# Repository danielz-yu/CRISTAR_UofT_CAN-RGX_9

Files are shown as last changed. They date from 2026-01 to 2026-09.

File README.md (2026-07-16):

# CRISTAR UofT | CAN-RGX 9

CRISTAR aims to investigate laser-induced crystallization under both microgravity and hypergravity conditions. Our project will use a compact laser cavitation system to generate crystals under different gravity environments. We will then compare the size, structure and purity of the resulting lysozyme crystals to determine how gravity influences morphology and structural characteristics. This work aims to reduce the cost of microgravity-grown crystals by leveraging short-duration suborbital flights. 

#

**Team Members:**
- Alexander Wainwright
- Khaled Madhoun
- Elias Barsa
- Gabriel Caribé
- Syeda Mahdia
- Lauren Altomare
- Daniel Yu
- Natalie Djuric

[Canadian Reduced Gravity Experiment Design Challenge | 2025-2026 Teams](https://www.seds.ca/can-rgx/#current)

#

### Setup and Run

Main GUI script: `cristar_gui.py`  
Required dependencies: `requirements.txt`

### 1. Local Setup

```bash
python3 -m venv .venv
source .venv/bin/activate
pip install --upgrade pip
pip install -r requirements.txt
```

### 2. Running the Main GUI

Aliases set up on the Raspberry Pi
```bash
connections
gui
connections
start
```

If these aliases are unavailable in a non-interactive shell, run the script directly:
```bash
/home/cristar/Documents/GUI_Development.venv/bin/python /home/cristar/Documents/GUI_Development/cristar_gui.py
```

### 3. Testing Scripts

The `testing/` folder contains helper/testing scripts.
```bash
python3 Connections.py
```

### 4. Raspberry Pi Quick Access

- Pi hostname/user: `cristar@cristar.local`
- Pi password: `cristar2026`
- Alias available on the Pi setup: `gui` (runs the main GUI)
```bash
ssh cristar@cristar.local
gui
```

### 5. Remote GUI from a Second Computer (SSH + Ethernet/Wi-Fi + X11)

If running the GUI remotely from another computer (for example over Ethernet), install XQuartz and launch with X11 forwarding:
```bash
open -a XQuartz
export DISPLAY=:0
ssh -Y -o ForwardX11=yes -o ForwardX11Trusted=yes cristar@cristar.local
gui
```

#

<br>

<p align="center">
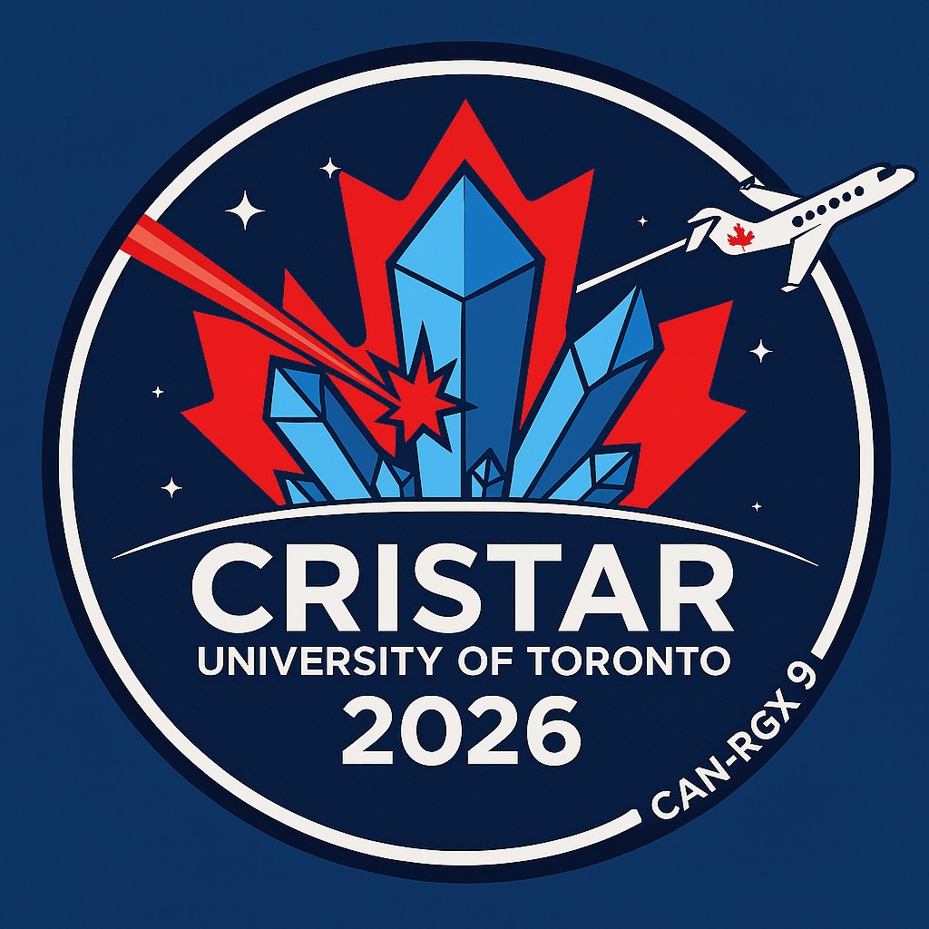
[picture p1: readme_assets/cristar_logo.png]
CRISTAR Logo
  </a>
  &nbsp;&nbsp;&nbsp;&nbsp;
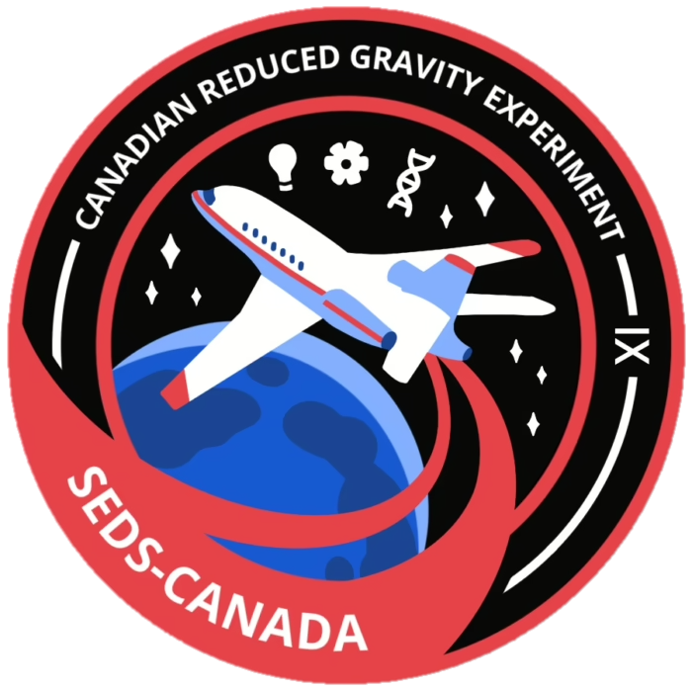
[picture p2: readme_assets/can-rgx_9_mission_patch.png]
CAN-RGX 9 Mission Patch
  </a>
</p>

<br>

<div align="center">
    <a href="https://www.seds.ca/can-rgx/">
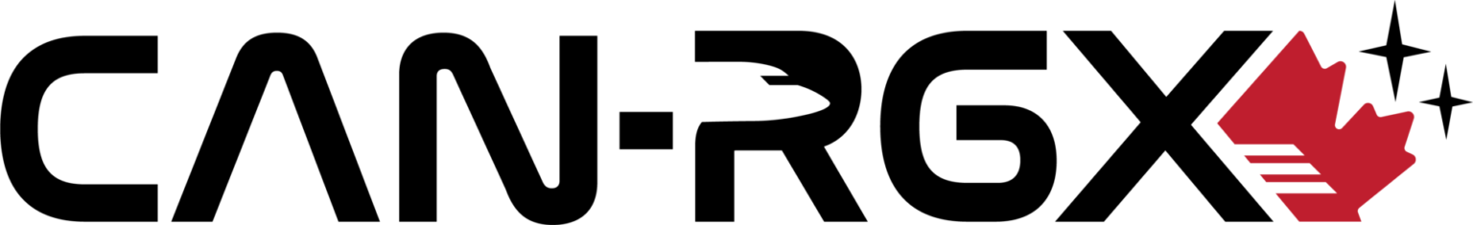
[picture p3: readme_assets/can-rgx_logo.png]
CAN-RGX Logo
        
    </a>
</div>

<br>

<div align="center">
    <a href="https://www.utoronto.ca/">
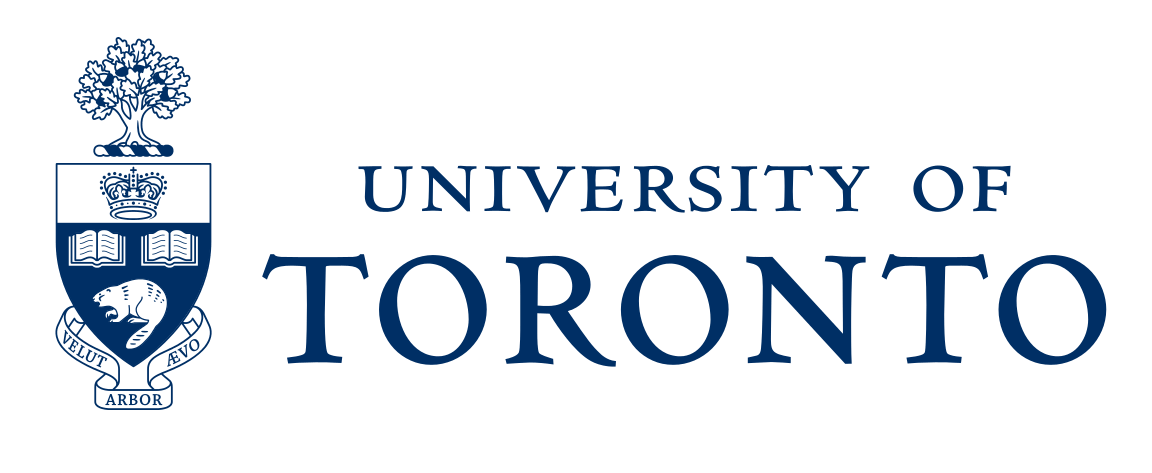
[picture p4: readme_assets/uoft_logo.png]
University of Toronto Logo
        
    </a>
</div>

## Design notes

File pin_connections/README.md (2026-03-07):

# Raspberry Pi 5 GPIO Connections

**SparkFun BME280**
- GPIO 1 (3V3)  --> 3V3
- GPIO 30 (GND) --> GND
- GPIO 2 (SDA)  --> SDA
- GPIO 3 (SCL)  --> SCL

**Adafruit BNO085**
- GPIO 1 (3V3)  --> VIN
- GPIO 39 (GND) --> GND
- GPIO 2 (SDA)  --> SDA
- GPIO 3 (SCL)  --> SCL

**Camera**

**Linear Stage**

**Laser**

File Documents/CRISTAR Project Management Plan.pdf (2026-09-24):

# Project Management Plan

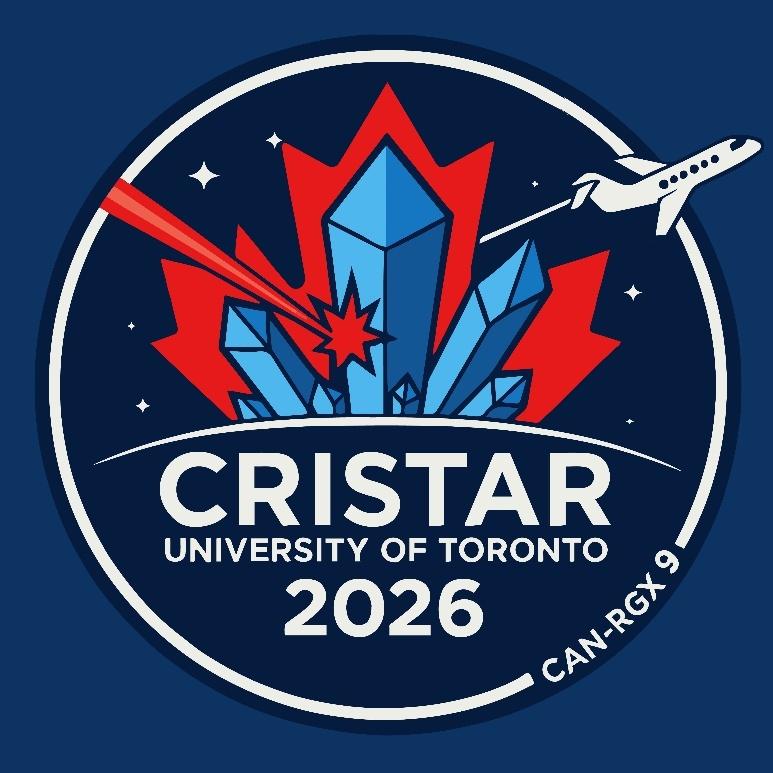
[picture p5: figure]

# CRISTAR

# University of Toronto

# Submitted in conformity with the requirements for the CAN-RGX IX program

# Submitted: December 30, 2025

# Executive Summary:

The CRISTAR project aims to study laser-induced crystallization under microgravity conditions as part of the CAN-RGX IX program. Crystallization is a critical process across multiple technological fields, and recent advances in laser-induced crystallization have enabled rapid, highly controlled crystal formation on Earth; however, the role of gravity in these processes remains poorly understood. By comparing the morphology and structural characteristics of crystals formed using laser-induced crystallization in a microgravity environment to those formed using the same technique on Earth, this project aims to advance the development of space-based crystallization techniques.

The CRISTAR team is composed of five undergraduate engineering students, two graduate physics students, and a supporting faculty advisor, all from the University of Toronto. To manage the technical requirements and timeline, the project is organized into five phases: design development, ground testing, pre-flight campaign, flight campaign, and post-flight review. Each phase includes clearly defined objectives, deliverables, and responsibilities, supported by a detailed work breakdown structure, timeline, and contingency protocols. Flight safety, laser safety, and experimental reliability are prioritized throughout the project lifecycle. A formal task reallocation and member recruitment process has been established to mitigate risks associated with team member availability and workload changes.

Budget requirements total $7,850 CAD, with a conservative fundraising target of $11,775 CAD after applying a 1.5x safety factor. Funding is pursued through a combination of “in-kind” donations, university funding programs, student organizational funding, and specialized industry support, with each member being responsible to secure funding for their area of expertise.

In parallel with technical objectives, the project emphasizes public engagement through ongoing in-person and digital outreach activities. These efforts aim to communicate the scientific and societal value of microgravity research to students and the broader community.

# Contents:

## Executive Summary: | 2 Introduction: Project Background | 4 Team structure and Management | 5 Team Members | 6 Task Reallocation Protocol | 7 Member Recruitment | 8 Project Timeline | 9 Time Management Protocol | 9 Project Time Allocation | 9 Budget and Funding | 13

Budget and funding strategy | Error! Bookmark not defined.

## References | 16

# List of Figures:

Figure 1: Work breakdown structure for project tasks and responsibilities for each member | 5
Figure 2: Step by step plan of action for task reallocation after a team member requests a reduction in
contribution expectations or is unable to continue their support of the CRISTAR project | 7
Figure 3:Step by step plan for the recruitment of team members which will be applied when new team

## members are required to support project goals | 8

# List of Tables:

Table 1: List of team members, including the faculty advisor, all from the University of Toronto, with

roles identified | 6 Table 2: Overview of the time allocations for each phase of the project | 10 Table 3: Time and task allocation for the design development phase | 11 Table 4: Time and task allocation for the ground testing phase | 12 Table 5: Time and task allocation for the flight campaign phase | 12 Table 6: Time and task allocation for the post flight phase of the project | 12

Table 7:Budget requirements for project components are travel costs are estimated and described. Shipping costs are planned to be covered by the Miller Lab and are not included in the budget below....14 Table 8: Funding Sources and Member Responsibilities: Each team member is accountable for securing resources related to their assigned engineering tasks. Responsibilities include identifying required
components and contacting suppliers to explore potential donations or discounts for those items | 15

# Introduction: Project Background

Crystallization is a foundational process in materials science, with applications in pharmaceutical drug development¹⁻⁵

, organic electronics⁶⁻⁸

, energy storage⁹,10, and semiconductor manufacturing¹¹. Interest in space-based crystallization processes is on the rise and has developed into a distinct part of the space industry¹²⁻¹⁶. A promising new ground-based technique involves laser-induced crystallization¹⁷, where short-lived bubbles rapidly reduce pressure and trigger nucleation. This method shortens crystal formation time from hours to seconds, with enhanced control over crystal size¹⁸, offering potential for high-throughput production of nano- and microcrystals¹⁸. However, the role of gravity in these dynamics, especially in laser-induced methods, remains poorly understood. Clarifying this influence is important for advancing space-based manufacturing and improving Earth-based simulations of space-grown materials.

This research aims to demonstrate laser-based crystallization in a microgravity environment and to compare the resulting crystal structures with those formed on Earth. The experiment will assess whether laser-induced crystallization under microgravity conditions accelerates crystal formation and enhances sample quality relative to Earth-grown crystals. These insights are particularly relevant for producing crystals suitable for diffraction-based structural determination using electron beams, which are now sufficiently compact and portable for spaceflight applications.

Key stakeholders include pharmaceutical companies that depend on high-quality crystals for drug development¹⁻⁵

, Canadian startups looking for new niches in the space industry¹⁹, and the Canadian Space Agency, which supports research that strengthens Canada’s role in the emerging space economy. Environmental considerations are also important. The proposed laser-based crystallization approach requires only short suborbital flights to produce thousands of samples, rather than relying on traditional orbital missions. Laser induced crystallization would reduce the number of satellites in low Earth orbit, mitigating space debris, require less fuel per flight, lower the overall environmental impact of space-based crystallization processes, and decrease operational costs.

The motivation behind this experiment is to lay the groundwork for scalable crystallization techniques in space, enabling space-based manufacturing, high-throughput screening and structural analysis using electron diffraction. By bridging fundamental science with engineering implementation, this research addresses critical questions about gravity’s role in materials science.

The goal of the proposed experiment is to demonstrate the production of microcrystals using laser cavitation-based crystallization in a short-duration microgravity environment, and to compare them to crystals produced using the same technique under Earth’s gravity. This objective includes demonstrating that laser-induced crystallization can reliably occur in microgravity and determining whether gravity influences the morphology and structural characteristics of the resulting crystals.

# Team structure and Management

CRISTAR is a team of seven students at the university of Toronto, with one faculty advisor. The team consists of two graduate students from the department of physics, and five undergraduate students from the Department of Engineering. To ensure the successful completion of our project objectives, task have been distributed as outlined in the work breakdown structure in Figure 1, with role assignment being given in Table 1. Roles were allocated according to areas of expertise and interest. We decided to have concrete roles to make job alignment and accountability straightforward. However, everyone is expected to help outside of their role when needed since interdisciplinary collaboration is at the centre of the team ethos.

The work breakdown structure in Figure 1 is written in terms of lines of effort instead of the five project phases to better illustrate the team workload distribution.

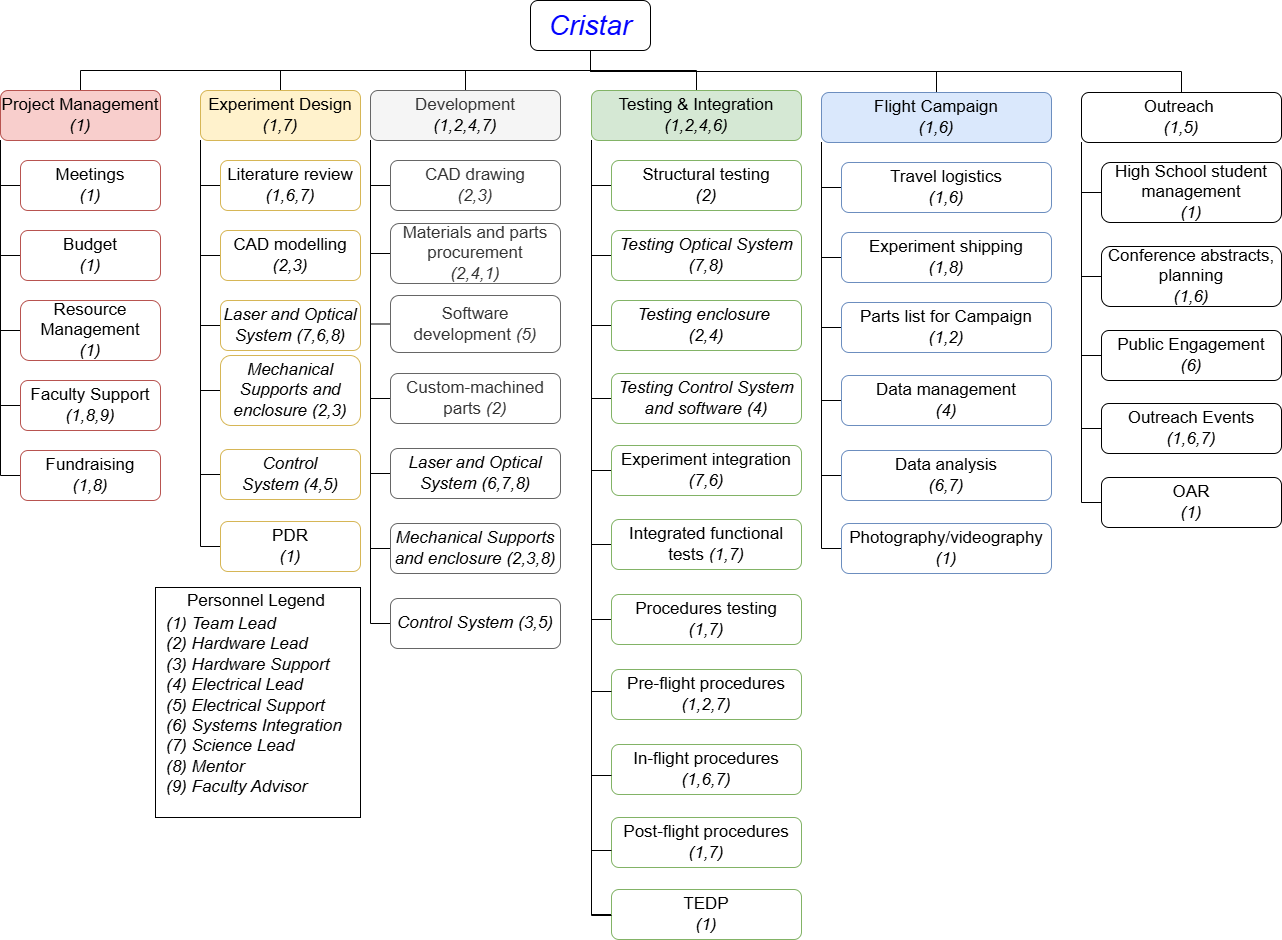
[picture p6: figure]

Figure 1: Work breakdown structure for project tasks and responsibilities for each member.

## Page 6/17

## Team Members

Table 1: List of team members, including the faculty advisor, all from the University of Toronto, with roles identified.

First, Last Name | Degree in progress | Level of Study | Department | Role | Email
Alexander, Wainwright | Ph.D. | Graduate | Physics | Team Lead | Alexander.Wainwright@mail.utoronto.ca
Syeda, Mahdia | BASc. | Undergraduate | Engineering Sciences | Science Lead | Syeda.Mahdia @mail.utoronto.ca
Lauren, Altomare | BASc. | Undergraduate | Engineering Sciences | Systems Integration | Lauren.Altomare@mail.utoronto.ca
Daniel, Yu | BASc. | Undergraduate | Computer Engineering | Electrical and Hardware Support | Danielz.Yu@mail.utoronto.ca
Elias, Barsa | BASc. | Undergraduate | Engineering Sciences | Hardware Lead | Elias.Barsa@mail.utoronto.ca
Gabriel, Caribe | BASc. | Undergraduate | Engineering Sciences | Electrical Lead | G.Caribe@mail.utoronto.ca
Khaled, Madhoun | Ph.D. | Graduate | Physics | Mentor | Khaled.Madhoun@mail.utoronto.ca
R.J. Dwayne, Miller | - | University Professor | Physics & Chemistry | Faculty Advisor | Dwayne.Miller@utoronto.ca

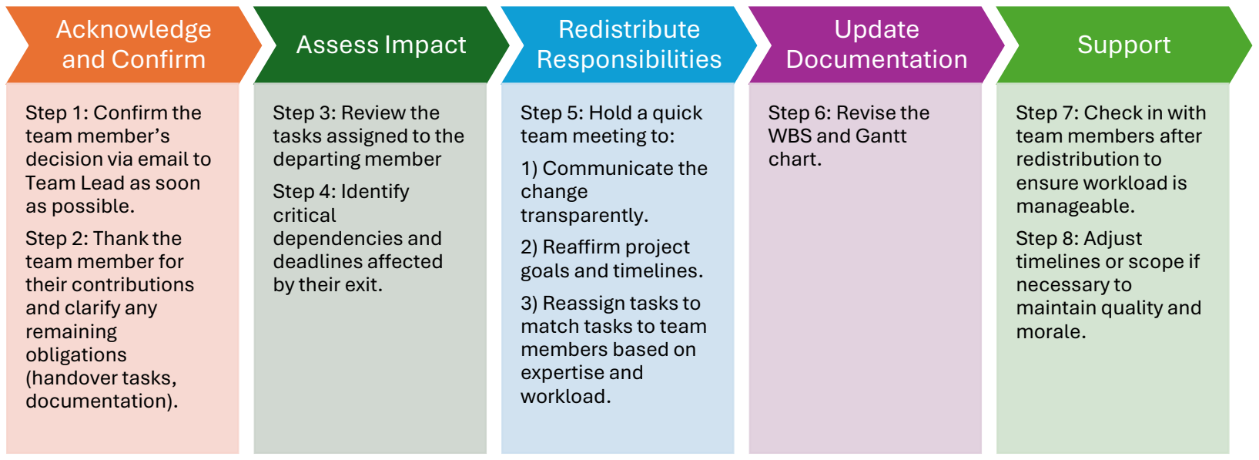
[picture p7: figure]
Acknowledge and Confirm; Step 1: Confirm the team member’s decision via email to Team Lead as soon as possible. Step 2: Thank the team member for their contributions and clarify any remaining obligations (handover tasks, documentation).; Assess Impact; Step 3: Review the tasks assigned to the departing member Step 4: Identify critical dependencies and deadlines affected by their exit.; Redistribute Responsibilities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

## Page 7/17

## Task Reallocation Protocol

Contingency planning is key to project success. As life changes may prevent CRISTAR members from continuing their commitment to the team, we have developed a task reallocation protocol, shown in Figure 2, to be followed if team members require a reduction in tasks or are unable to continue their commitment to the project.

Figure 2: Step by step plan of action for task reallocation after a team member requests a reduction in contribution expectations or is unable to continue their support of the CRISTAR project.

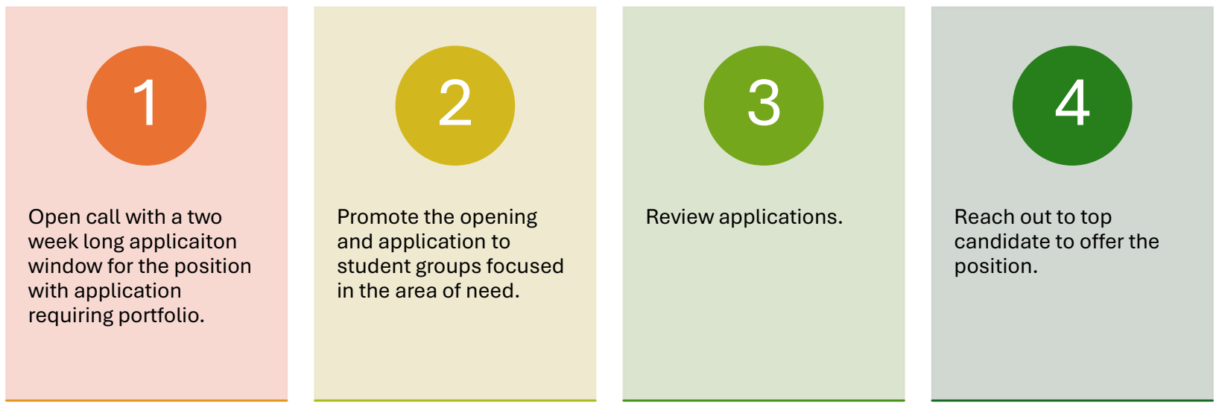
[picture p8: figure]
Open call with a two week long applicaiton window for the position with application requiring portfolio.; Promote the opening and application to student groups focused in the area of need.; Review applications.; Reach out to top candidate to offer the position.

## Page 8/17

## Member Recruitment

As the project develops, there may be a need to recruit new members. In such situations, the steps outlined in Figure 3 will be used to find a suitable candidate. Currently, we are reviewing applications for a social media position on the team. This individual will provide the online media presence for CRISTAR and help run outreach activities.

Figure 3:Step by step plan for the recruitment of team members which will be applied when new team members are required to support project goals.

# Project Timeline

## Time Management Protocol

The team will maintain schedule adherence through structured planning and proactive monitoring. A detailed project timeline with defined milestones has been established, supported by a Gantt chart (https://docs.google.com/spreadsheets/d/1Dol3yYh2MeKFbOglesCjhAFllKaS52ni/edit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) for realtime visibility (examples seen in Tables 2-6 below). Weekly team meetings, led by the Team Leader, will begin with a progress review, highlighting completed tasks and upcoming milestones to ensure alignment with the project plan. The Gantt chart will be reviewed and updated during these meetings to provide a clear visual reminder of progress and deadlines. Each design leader will be responsible for identifying which tasks are essential to meeting project objectives versus extra or optional tasks, allowing the team to make informed decisions on where time can be saved if necessary. Time allocation will follow a strict priority order: flight safety first, followed by scientific considerations, then media and outreach activities. Contingency buffers will be integrated into critical path activities to mitigate potential risks, and any emerging issues will be addressed promptly during these reviews.

To reinforce accountability and efficiency, the Team Leader will coordinate closely with all members to ensure tasks are completed on time and resources are optimally allocated. Clear communication channels (Google Drive for file transfer, and communication via the team WhatsApp and Discord channel) will be maintained to provide timely updates and resolve bottlenecks before they impact the schedule. Each team member will be responsible for accurate progress reporting and collaborating effectively to meet deadlines, while the Team Leader will oversee adherence to the timeline and implement minor adjustments as needed to keep the project on track.

## Project Time Allocation

Given the short timeline and demanding engineering requirements, the project has been divided into five distinct phases: design development, ground testing, pre-flight campaign, flight campaign, and post-flight review. During the design development phase, we will create detailed concepts for each component of the microgravity system. Each component will first undergo independent testing to ensure compliance with program requirements and scientific objectives. Once verified, the components will be integrated for ground testing, where we will assess overall system performance against engineering standards for flight safety, laser safety, and experimental reliability. Following ground testing, the pre-flight campaign phase will simulate in-flight procedures on the ground to validate operational readiness. The system will then be deployed for microgravity flights and experiment execution. Finally, in the post-flight review phase, we will analyze results, publish findings, and support ongoing public outreach. In parallel with these engineering objectives, we will conduct both in-person and digital outreach programs to engage the broader community. Details as to task and time allocations for the project are given in Tables 2-6 below.

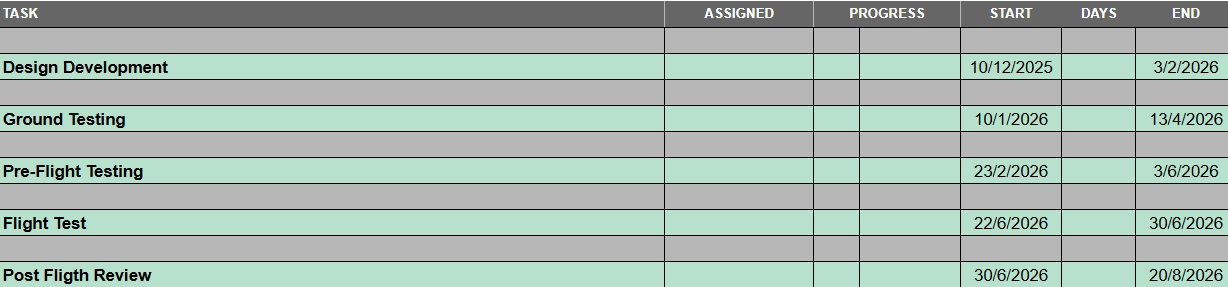
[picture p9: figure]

## Page 10/17

Table 2: Overview of the time allocations for each phase of the project.

## Page 11/17

Table 3: Time and task allocation for the design development phase.

TASK | ASSIGNED | START | END
Design Development | | 10/12/2025 | 3/2/2026
Structure and Organization Development | Alex | 10/12/2025 | 15/12/2025
Finish Verification and Compliance Matrix | Alex | 15/12/2025 | 22/12/2025
Preliminary Design Development (Optical system) | Syeda & Khaled | 22/12/2025 | 5/1/2026
Preliminary Design Development (Science) | Alex | 22/12/2025 | 5/1/2026
Preliminary Design Development (Electrical) | Gabriel | 22/12/2025 | 5/1/2026
Preliminary Design Development (Hardware) | Elias | 22/12/2025 | 5/1/2026
Preliminary Design evaluation and selection (Optical system) | Syeda & Khaled | 5/1/2026 | 6/1/2026
Preliminary Design evaluation and selection (Samples) | Lauren | 5/1/2026 | 6/1/2026
Preliminary Design evaluation and selection (Electrical) | Gabriel &
| Daniel | 5/1/2026 | 6/1/2026
Preliminary Design evaluation and selection (Mechanical) | Elias & Daniel | 5/1/2026 | 6/1/2026
Flight Procedure Development | Syeda & Lauren | 10/12/2025 | 5/1/2026
Ground Test Plan Development | Elias & Gabriel | 5/1/2026 | 3/2/2026
Check design with SMEs (Particular attention to fasteners, loads, and laser safety) | Alex | 6/1/2026 | 12/1/2026
Preliminary Design stress test on CAD (Mechanical) | Elias | 5/1/2026 | 11/1/2026
Budget and Fundraising Finalization | Alex | 6/1/2026 | 12/1/2026
Outreach Plan Finalization | Alex | 10/12/2025 | 10/1/2026
PDR 1 and Test Equipment Data Package Rev 1 | Alex | 6/1/2026 | 10/1/2026

## Page 12/17

Table 4: Time and task allocation for the ground testing phase.

TASK | ASSIGNED | START | End
Ground Testing | | 10/1/2026 | 13/4/2026
Order parts | Alex | 6/1/2026 | 7/1/2026
Optical System and interlock Prototype | Khaled | 6/1/2026 | 19/1/2026
Prototype Crystal generation | Alex | 6/1/2026 | 4/2/2026
Prototype electrical design | Gabriel | 6/1/2026 | 4/2/2026
Prototype Mechanical design | Elias & Daniel 6/1/2026 | 4/2/2026
Stress test Mechanical Design | Elias | 4/2/2026 | 10/2/2026
Stress test integrated Electrical Design | Khaled | 4/2/2026 | 10/2/2026
Preliminary Design Review | Alex | 20/2/2026 | 23/2/2026
Integrate components | Lauren | 10/2/2026 | 16/2/2026
Stress test total system | Elias | 16/2/2026 | 1/3/2026
PDR 1 and Test Equipment Data Package Rev 2 | Alex | 10/4/2026 | 13/4/2026

Table 5: Time and task allocation for the flight campaign phase.

TASK | ASSIGNED | START | End
Flight Campaign | | 22/6/2026 | 30/6/2026
Flights | Alex | 22/6/2026 | 30/6/2026
Electron Diffraction | Syeda | 30/6/2026 | 29/7/2026

Table 6: Time and task allocation for the post flight phase of the project.

TASK | ASSIGNED | START | End
Post Flight Review | | 30/6/2026 | 20/8/2026
Post Flight Survey | Alex | 30/6/2026 | 22/7/2026
Outreach Activity Report | Alex | 30/6/2026 | 7/8/2026
Manuscript writing | Alex | 22/7/2026 | 20/8/2026

# Budget and Funding

Major budget requirements for the project include material costs for essential components, travel expenses, accommodation for the flight campaign, and shipping costs for transporting project components to and from the National Research Council (NRC). These expenses have been estimated and summarized in Table 2, with the total project cost projected at $7,850 CAD. To ensure sufficient funds are available, a factor of safety of 1.5 has been applied, resulting in a fundraising goal of $11,775 CAD. To date, significant support has been received from the Miller Lab at the University of Toronto and the Laser Safety Team, reducing costs by $1,050 CAD. Consequently, the current fundraising goal stands at $10,200 CAD.

Our funding strategy focuses on three key approaches: Connecting, Applying, and Collaborating. First, we aim to connect with corporations to secure “in-kind” support by requesting optical / mechanical components and seeking discounts where donations are not possible. Second, we will apply for financial assistance through university funding programs and student organizational funding opportunities to ensure adequate resources for the project. Finally, we plan to collaborate with industry stakeholders by requesting specialized support, such as partnering with Hitachi for nano-crystallography work. These combined efforts will help us secure both material and financial resources while fostering strategic partnerships. An overview of our funding requests are in Table 8. At the time of writing only two university funding programs have been secured. The most time sensitive funding sources currently are the “in-kind” requests to component manufacturers: Thorlabs, Zaber, McMaster-Carr, and Kentek. These requests have not been sent yet at time of writing, but the relevant team member will reach out to each company in conjunction with ordering the required parts by the January 7

th deadline. The aim is to send out all further funding requests to the university and collaborating companies by the end of January.

Table 7:Budget requirements for project components are travel costs are estimated and described. Shipping costs are planned to be covered by the Miller Lab and are not included in the budget below.

Item | Description | Estimated Cost (CAD)
Translation Stages | Stages to move the crystallization sample between trials. | $3000.00
Camera | Camera to image the cavitation process in the crystallization solution | $500.00
Focusing System | Lens or mirror to focus the laser light inside the crystallization solution to drive cavitation. | $2000.00
Camera Mount | Mount to hold the camera security and withstand the strong acceleration forces present during parables. | $300.00
Interlock system | System to shut down the operations of the laser if the laser chamber is opened. | $50.00
Enclosure materials | Laser safe materials required to enclose the cavitation chamber. | $500.00
Metal for Fixed Optics | Materials to fix and hold optics in place in the high acceleration environment of the experiment. | $500.00
Travel Costs | Travel for one week in the Ottawa area for the flight campaign phase of the project. | $1000.00
Total Cost | | $7850.00

Table 8: Funding Sources and Member Responsibilities: Each team member is accountable for securing resources related to their assigned engineering tasks. Responsibilities include identifying required components and contacting suppliers to explore potential donations or discounts for those items.

Funding Source | Member Responsible | Confirmed (Y/N) | Amount Expected (CAD) | Amount Received (CAD)
SPIE Student Chapter | Alex | Yes | $1000 | $1000.00
Humans Learning Machine Learning | Alex | Yes | $200 | $200.00
Massey College | Alex | No | $100 | $0.00
Physics Department | Khaled | No | $100 | $0.00
Department of Chemistry | Khaled | No | $100 | $0.00
Thorlabs | Gabriel | No | $3000 | $0.00
Zaber | Syeda | No | $300 | $0.00
McMaster-Carr | Elias | No | $1000 | $0.00
Kentek | Syeda | No | $500 | $0.00
EngSoc CPSIF Funding | Lauren | No | $200 | $0.00
Student Initiative Funding | Lauren | No | $500 | $0.00
Light Matter Interaction Inc. | Alex | No | $200 | $0.00
Hitachi | Faculty Advisor | No | $1000 | $0.00
Total Funding | | | $10900 | $1200.00

# References

1. Reichert, P. et al. Pembrolizumab microgravity crystallization experimentation. npj Microgravity 5, 28 (2019).
2. McPherson, A. & DeLucas, L. J. Microgravity protein crystallization. NPJ Microgravity 1, 15010 (2015).
3. Orehek, J., Teslić, D. & Likozar, B. Continuous Crystallization Processes in Pharmaceutical Manufacturing: A

Review. Org. Process Res. Dev. 25, 16–42 (2021).

4. Mukherjee, S. Chapter 2 - Isolation and Purification of Industrial Enzymes: Advances in Enzyme Technology.

in Advances in Enzyme Technology (eds. Singh, R. S., Singhania, R. R., Pandey, A. & Larroche, C.) 41–70

(Elsevier, 2019). doi:10.1016/B978-0-444-64114-4.00002-9.

5. Crystallizing Proteins in Space Helping to Identify Potential Treatments for Diseases - NASA.

https://www.nasa.gov/missions/station/iss-research/crystallizing-proteins-in-space-helping-to-identify-

potential-treatments-for-diseases/ (2022).

6. Peng, B., Wu, R. & Li, H. Crystallization from a Droplet: Single-Crystalline Arrays and Heterojunctions for

Organic Electronics. Acc. Chem. Res. 54, 4498–4507 (2021).

7. Yu, P., Zhen, Y., Dong, H. & Hu, W. Crystal Engineering of Organic Optoelectronic Materials. Chem 5, 2814–

2853 (2019).

8. Johnson, H. M. et al. Discovery of Crystallizable Organic Semiconductors with Machine Learning. J. Am.

Chem. Soc. 146, 21583–21590 (2024).

9. Dong, W. & Huang, F. Understanding the influence of crystal packing density on electrochemical energy

storage materials. eScience 4, 100158 (2024).

10. Zhang, R. et al. Balancing volumetric and gravimetric capacity for hydrogen in supramolecular crystals. Nat.

Chem. 16, 1982–1988 (2024).

11. Wilkinson, A. R. et al. A meta-analysis of semiconductor materials fabricated in microgravity. npj

Microgravity 10, 73 (2024).

12. Redwire to Develop Space-Based Drug Development and Manufacturing Platform. Redwire Space

https://rdw.com/newsroom/redwire-to-develop-space-based-drug-development-and-manufacturing-platform/

(2022).

13. Crystal Growth. ISS National Lab https://issnationallab.org/research-and-science/space-research-

overview/research-areas/in-space-production-applications/crystal-growth/.

14. Differentiated drug products enabled by microgravity • Varda Space Industries. Varda Space Industries

https://www.varda.com/biopharma/.

15. Varda raises $187M to scale in-space drug crystallization lab | Pharma Manufacturing.

https://www.pharmamanufacturing.com/industry-news/news/55302723/varda-raises-187m-to-scale-in-space-

drug-crystallization-lab.

16. Mulligan, M. K., Tuma, S., Mullins, S., Savin, K. A. & Wilson, A. Protein Crystallization in Microgravity:

Commercialization and the Next Chapter. Curr Stem Cell Rep 11, 6 (2025).

17. Korede, V. et al. A Review of Laser-Induced Crystallization from Solution. Crystal Growth & Design 23,

3873–3916 (2023).

18. Nikbin, E. et al. Femtosecond Laser-Induced Crystallization of Cytosine Monohydrate for Serial Nano Electron

Diffraction Analysis. Microscopy and Microanalysis vol. 31 (2025).

19. Mortillaro, N. Canadian companies race to launch rockets into orbit from home soil — a first. CBC News

(2025).

20. Wright, H. et al. An Analysis of Publicly Available Microgravity Crystallization Data: Emergent Themes

Across Crystal Types. Crystal Growth & Design 22, 6849–6851 (2022).

21. Pal, K. & Radocea, A. Gravity as a Knob for Tuning Particle Size Distributions of Small Molecules. Crystal

Growth & Design 24, 2370–2383 (2024).

22. Timofeev, V. I., Ivanovsky, A. S., Marchenkova, M. A., Rakitina, T. V. & Kuranova, I. P. Growth of protein

crystals in microgravity: history and present status. Crystallography Reviews 30, 236–260 (2024).

23. Paulson, J. et al. Microgravity-Grown Crystals as Seeds for Pharmaceutical Compounds. Crystals 15, 825

(2025).

24. Takahashi, S. et al. JAXA protein crystallization in space: ongoing improvements for growing high-quality

crystals. J Synchrotron Radiat 20, 968–973 (2013).

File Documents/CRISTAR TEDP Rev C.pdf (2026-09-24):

TEDP-Rev C.


## CRISTAR University of Toronto Submitted in conformity with the requirements for the CAN-RGX IX program

## Submitted: 08/12/2026

## Executive Summary

The final TEDP for the CRISTAR project outlines our aim to study laser-induced crystallization under microgravity conditions as part of the CAN-RGX IX program. Crystallization is a critical process across multiple technological fields, and recent advances in laser-induced crystallization have enabled rapid, highly controlled crystal formation on Earth; however, the role of gravity in these processes remains poorly understood. By comparing the morphology and structural characteristics of crystals formed using laser-induced crystallization in a microgravity environment to those formed using the same technique on Earth, this project aims to advance the development of space-based crystallization techniques.

The CRISTAR team is composed of seven undergraduate students, two graduate physics students, and a supporting faculty advisor, all from the University of Toronto. To manage the technical requirements and timeline, the project is organized into five phases: design development, ground testing, pre-flight testing, flight campaign, and post-flight review. The team has completed the pre-flight testing. The flight test phase will take place on the week of August 31st, 2026. Each phase includes clearly defined objectives, deliverables, and responsibilities, supported by a detailed work breakdown structure, timeline, and contingency protocols. Flight safety, laser safety, and experimental reliability are prioritized throughout the project lifecycle.

The TEDP outlines the final technical design with CAD models, images of the final design, the results from the preflight testing which verified that the final project meets the project design requirements.

## Contents

16.2 Project Time Allocation | 44
17.0 Budget and Funding | 48
18.0 Outreach Activity Report | 50
19.0 References | 55
Appendix A: Risk Assessment Tables | 57
A 1.0 Human Risks (HRs): | 57
A 2.0 Managerial Risks (MRs): | 58
A 3.0 Technical Risks (TRs): | 60
Appendix B: Laser Safety Calculations | 63
B 1.0 Laser Specifications | 63
B 2.0 Laser Safety information | 63
B 3.0 Nominal Ocular Hazard Distance (NOHD) | 64
B 4.0 Nominal Hazard Zone (NHZ) | 65
B 5.0 Optical Density (OD) | 65
B 6.0 Conclusions | 65
Appendix C: Safety Data Sheets (SDSs) | Error! Bookmark not defined.
Appendix C: Flight Procedure Flowcharts | 66

List of Tables:
Table 1: Bill of materials for CRISTAR microgravity Flights | 17
Table 2: Mass Budget for CRISTAR Project | 18
Table 3: Electrical load table for the CRISTAR project | 20
Table 4: Science traceability matrix for microgravity laser induced crystallization | 21
Table 5: Protein Crystallization solution spills | 35
Table 6: Power loss hazard table | 36
Table 7: Translation stage failure hazard table | 37
Table 8: Loss of Connections with laser | 38
Table 9: Structural failure or deformation of the Mirror Mount | 39
Table 10: Loss of laser light confinement risk table | 40
Table 11: Risk Assessment Matrix | 42
Table 12: List of team members, including the faculty advisor, all from the University of Toronto, with roles
identified | 43
Table 13: Preliminary Design Schedule | 45
Table 14: Ground test schedule | 46
Table 15: Preflight testing schedule | 47
Table 16: Flight test schedule | 47
Table 17: Budget requirements for project components are travel costs are estimated and described. Shipping costs are planned to be covered by the Miller Lab and are not included in the budget below. Final costs for travel to the travel campaign have not been accumulated to date, resulting in the use of the estimated costs (~) for the
total expenditure for the CRISTAR project | 49
Table 18: Funding Sources are listed with green representing secured funds with total expenditure in red | 50
Table 19: Team member unavailability Risk Assessment Table | 57
Table 20: Errors in experimental setup or execution due to human mistakes risk assessment table | 57

Table 21: Inadequate knowledge transfer | 58
Table 22: Transportation to Campaign site risk assessment table | 58
Table 23: Schedule slips due to unforeseen technical or administrative delays | 59
Table 24: Inefficient task allocation or overloaded team members | 59
Table 25: Spillage or loss of samples | 60
Table 26: Loss of optical alignment | 60
Table 27: Crystal cracking or No Crystal Formation | 61
Table 28: Electrical system failure under microgravity or high acceleration | 61
Table 29: Camera failure or poor image acquisition | 62
Table 30: Data corruption or loss during flight | 62
Table 31: Manufacturer Performance Specifications from the manufacturer data sheet and operations manual. .63
Table 32: Maximum permissible exposure values for between 2.6 µm and 1000 µm from ANSI Z136.1 | 63

Table of Figures:
Figure 1: Block Diagram of the system architecture used to produce crystals using laser-induced crystallization.9
Figure 2: Conceptual diagram of the interlock system including a bypass for laser initialization | 11
Figure 3: Photographs of the prototype laser bypass system. (A) Laser bypass activation switch with the external pin inserted, holding down the interlock button. (B) External pin installed through the Ethernet passthrough port, maintaining the interlock in the engaged position during laser startup. (C) Laser bypass activation switch with the pin removed, releasing the interlock button. The actuation lever is positioned below the pin hole, preventing re-engagement of the bypass without opening the enclosure. (D) External view of the passthrough port. (E) System during operation with indicator light on. (F) Open pin port in a dark environment, demonstrating that no
light escapes through the port | 12
Figure 4: PCB model holding the two sensor boards | 14
Figure 5: Side cut view of the CAD model of the pelican case structure showing the interlocks and laser system
in blue | 15
Figure 6: Interlock system for the pelican case enclosure | 15
Figure 7: CAD model of the sample and translation stage system | 16
Figure 8: Final Physical design | 16
Figure 9: Graphical representation of the electrical power and control system featuring exclusively commercial
off the shelf components | 19
Figure 10: Graphical User Interface screen shot from GUI demonstration video | 22
Figure 11: Mirror Mount Setup for Yield Point Determination and Load Testing | 31
Figure 12: PLA Mirror Mount Deformation under incremental cantilever loading. Dashed line indicates the
0.5mm functional yield point as defined | 32
Figure 13: Work breakdown structure for project tasks and responsibilities for each member | 44
Figure 14: Outreach social media accounts: Left) LinkedIn profile, Right) Instagram account | 52
Figure 15: CRISTAR’s presentation at the 2026 UTECHS Conference, Bahen Centre | 53
Figure 16: CRISTAR website, hosted as a subsection of the UofT Photonics Innovation Centre page | 53
Figure 17: Demonstrations at the 2026 OSSP Lab Tour, Lash Miller Chemical Laboratories | 54

7

## 1.0 Flight Manifest

Note: The primary mission specialists will be on the first flight and back up mission specialists on the second flight.

First and Last Name | Level of study | Program | Email | Campaign Status
Gabriel Caribe | Undergraduate | Engineering Sciences | G.Caribe@mail.utoronto.ca | Mission Specialist (Primary)
Syeda Mahdia | Undergraduate | Engineering Sciences | Syeda.Mahdia@mail.utoronto.ca | Mission Specialist (Primary)
Elias Barsa | Undergraduate | Engineering Sciences | Elias.Barsa@mail.utoronto.ca | Ground Crew (Back up Mission Specialist)
Alexander Wainwright | Graduate | Physics | Alexander.Wainwright@mail.utoronto.ca | Ground Crew (Back up Mission Specialist)
Natalie Djuric | Undergraduate | Astro Physics | N.Djuric@mail.utoronto.ca | Ground Crew
Khaled Madhoun | Graduate | Physics | Khaled.Madhoun@mail.utoronto.ca | Ground Crew
Ian Mo | Undergraduate | Computer Science | Ian.Mo@mail.utoronto.ca | Ground Crew
Lauren Altomare | Undergraduate | Engineering Sciences | Lauren.Altomare@mail.utoronto.ca | Not Attending
Daniel Yu | Undergraduate | Computer Engineering | Danielz.Yu@mail.utoronto.ca | Not Attending

## 2.0 Experimental Background

Crystallization is a foundational process in materials science, with applications in pharmaceutical
drug | development¹⁻⁵
, | organic | electronics⁶⁻⁸
, | energy | storage⁹,10, | and | semiconductor
manufacturing¹¹. Interest in space-based crystallization processes is on the rise and has developed into a distinct part of the space industry¹²⁻¹⁶. A promising new ground-based technique involves laser-induced crystallization¹⁷, where short-lived bubbles rapidly reduce pressure and trigger nucleation. This method shortens crystal formation time from hours to seconds, with enhanced control over crystal size¹⁸, offering potential for high-throughput production of nano- and microcrystals¹⁸. However, the role of gravity in these dynamics, especially in laser-induced methods, remains poorly understood. Clarifying this influence is important for advancing space-based manufacturing and improving Earth-based simulations of space-grown materials.
This research aims to demonstrate laser-based crystallization in a microgravity environment and to compare the resulting crystal structures with those formed on Earth. The experiment will assess whether laser-induced crystallization under microgravity conditions accelerates crystal formation and enhances sample quality relative to Earth-grown crystals. These insights are particularly relevant for producing crystals suitable for diffraction-based structural determination using electron beams, which are now sufficiently compact and portable for spaceflight applications¹⁹
Key stakeholders include pharmaceutical companies that depend on high-quality crystals for drug development¹⁻⁵

, Canadian startups looking for new niches in the space industry²⁰, and the Canadian Space Agency, which supports research that strengthens Canada’s role in the emerging space economy. Environmental considerations are also important. The proposed laser-based crystallization approach requires only short suborbital flights to produce thousands of samples, rather than relying on traditional orbital missions. If successful, laser-induced crystallization techniques may provide an alternative pathway for some space-based crystallization applications that could reduce dependence on long-duration orbital missions.
The motivation behind this experiment is to lay the groundwork for scalable crystallization techniques in space, enabling space-based manufacturing, high-throughput screening and structural analysis using electron diffraction. By bridging fundamental science with engineering implementation, this research addresses critical questions about gravity’s role in materials science. The goal of the proposed experiment is to demonstrate the production of microcrystals using laser cavitation-based crystallization in a short-duration microgravity environment, and to compare them to crystals produced using the same technique under Earth’s gravity. This objective includes demonstrating that laser-induced crystallization can reliably occur in microgravity and determining whether gravity influences the morphology and structural characteristics of the resulting crystals.

## 3.0 Experimental Design

To investigate the role of gravity in laser-based crystallization, the experiment uses a compact laser cavitation system designed for safe and reliable operation in a microgravity environment (see Figure 1). The system consists of five main subsystems: the laser optical system, the fluid handling system, cavitation monitoring sensors, the control and data acquisition system, and the enclosure.

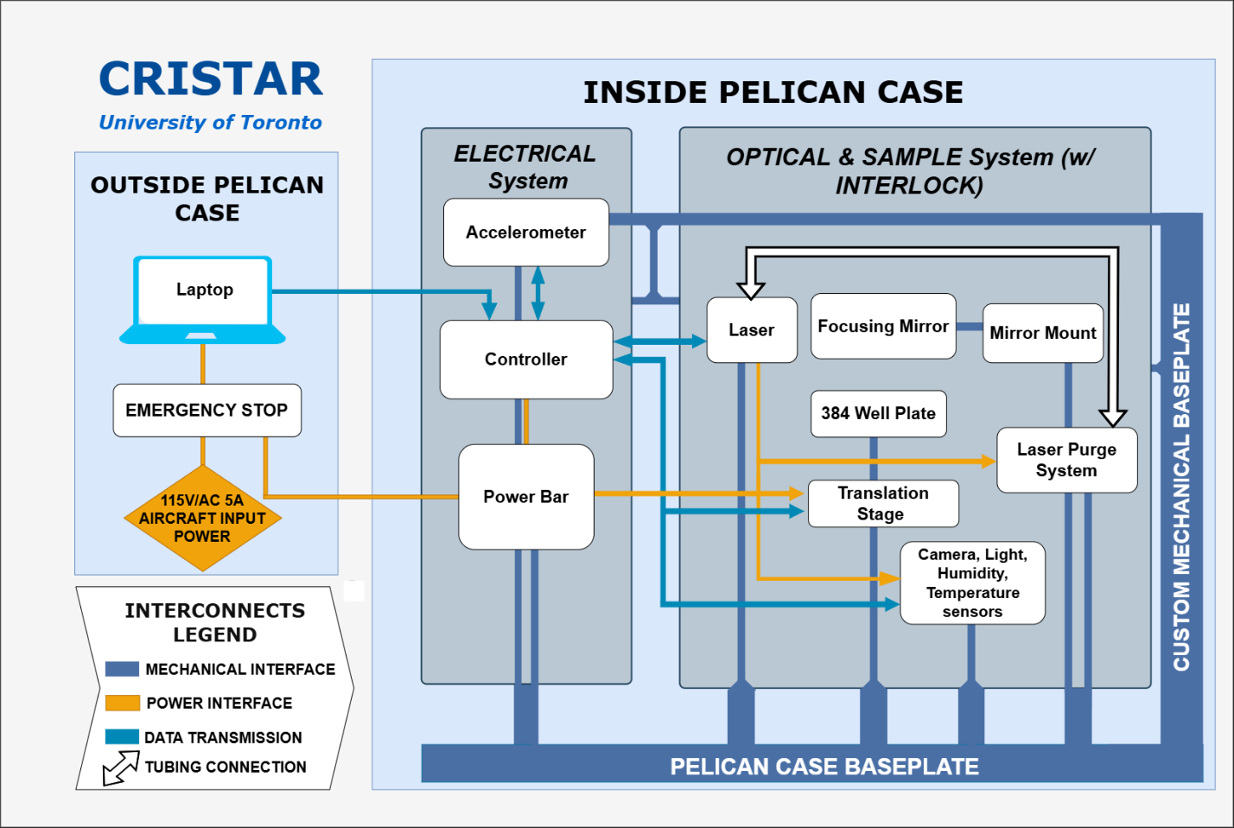
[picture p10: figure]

Figure 1: Block Diagram of the system architecture used to produce crystals using laser-induced crystallization.

## 3.1 Mechanical Mounting:

The laser optical system is rigidly mounted to the bottom panel of the Pelican case using vibration-damping brackets to minimize oscillations during parabolic maneuvers. The laser module is bolted directly to the base plate of the chamber, with a focusing mirror aligned along the optical axis. The focusing mirror is mounted to a holder which is made from PLA and attached directly to the base plate, ensuring stable alignment with the laser beam path. A 384-well plate, containing the crystallization solution, is positioned at the focus of the optical system on a motorized linear translation stage (one-dimensional translation with a minimum step size of 500 µm). The linear translation stage is secured to the pelican case base plate using threaded fasteners and vibration-isolating spacers. The laser beam is focused through an off axis parabolic mirror into the wells, with the optical path enclosed by a laser-safe housing with a magnetic interlock system. These interlocks ensure the laser can only operate when the housing is fully closed, maintaining Class 1 laser safety compliance.
To monitor the laser cavitation conditions an accelerometer, temperature and humidity sensor array is mounted to the supporting shelf inside the Pelican case. A CCD camera is used to monitor the cavitation process and is fixed to the supporting shelf to provide a stable view of the well plate. An LED light is also included as part of the camera system and mounted to the supporting shelf to provide sufficient lighting inside the box.

## 3.2 Electrical and Data Connections:

Components draw power from the aircraft’s 115 VAC, 5 A supply, routed through a power strip inside the case. The total system load is less than 600 W (see Table 3).

## 3.3 Laser Module:

The Ivy laser is powered from a single 24V output 90W power supply, equipped with a standard IEC320-C14 inlet and adapting to the input voltage in the range of 90VAC to 264VAC. The power supply contains an overload protection (hiccup mode), an over voltage protection (re-power required) and an over temperature protection (re-power required). Once the laser is powered, the internal electronics check that the interlock is closed. When they are open, laser emission is disabled. The laser will check all internal modules for proper communication and status, in this period the status LED is blinking in orange. Once all internal modules are cleared the laser is ready to receive commands and the status LED is breathing slowly in green. Note that the laser cannot be initialized until an external command is given and there is no manual way to initialize the laser head.
To initialize the laser, it must be put in “standby mode”. In this mode the laser will thermalize, i.e. all components are brought to the defined temperature. During thermalization, the status LED is flashing green at a frequency of about 2 Hz and the GUI. This thermalization process can take up to 10 minutes, depending on the ambient conditions. Once thermalization is complete, the status LED will shine firmly green, and the laser is ready for emission. The laser is already rated laser class 3b in this mode.
The laser can be put into standby mode by either using the manufacturer’s GUI or using a command passed through ethernet. For the CRISTAR project, commands are given from the Raspberry Pi located inside the pelican case. This Raspberry Pi is controlled through an ethernet cable which is connected to a laptop on the outside of pelican case. The connection is run through a VNC which give a virtual desktop like control of the Raspberry Pi. Without connecting to the raspberry pi, there is no control inputs given to the laser. As such, the laser cannot be put into “standby mode” until the command is given from the Pi, which passed to the Pi through the ethernet port throughput on the pelican case.
To meet program requirements, the laser is enclosed in a laser safe box with an interlock, meeting Class 1 laser compliance.
3.3.1 Laser interlock system:

The laser is equipped with an interlock connector. Unless pin 1 and pin 3 of the connector are connected, laser emission is disabled. This interlock connector should be connected to the user’s safety circuit, in this case two magnetic interlocks (ENTRY-GUARD™ Magnetic Non-Contact Safety Interlock, ETG-INLK-L/R) on the inside of the pelican case.

Early experiments with the interlock system on the pelican case used magnets to bypass the interlock system for initialization. The laser was then shutdown and the bypass removed before closing the box to engage the interlock. Then the system was rebooted before the laser could identify that the interlock was broken. When interlock was left open for longer than about a minute with the laser shutdown, the interlocks would need to be reset by cycling the key inside the pelican case, which required opening the interlocks. In the case of the microgravity flight campaign, the laser will have to be unpowered for an extended period before integration, meaning that an interlock bypass will be required to allow for the key at the back of the laser to be cycled before the box is closed.
The interlock bypass must ensure that the laser cannot be initialized or operated while the box is open. We accomplish this through the following system:

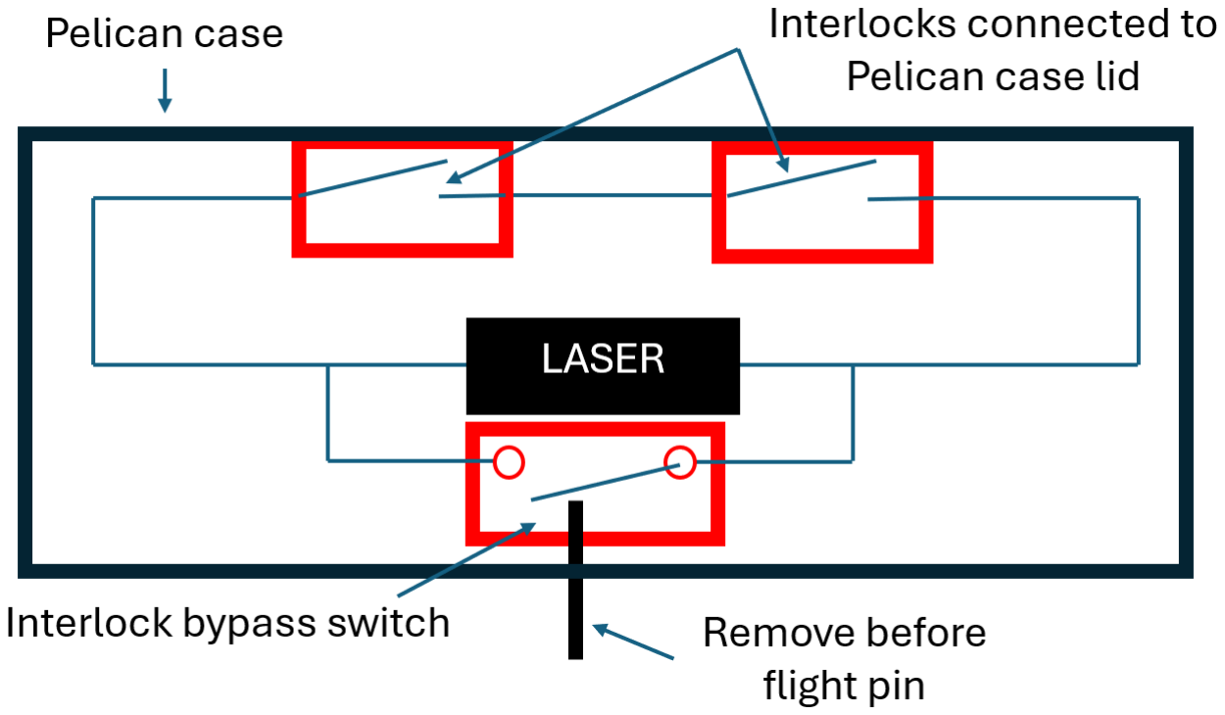
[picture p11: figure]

Figure 2: Conceptual diagram of the interlock system including a bypass for laser initialization.
Where the remove before flight pin blocks the ethernet connection port to the raspberry pi, preventing the laser from being enabled or thermalized when the interlock bypass is closed. The interlock bypass switch is configured such that the interlock bypass switch cannot be reset while the pelican case is closed. As such, it is not possible to open the box with the laser enabled or thermalized as opening the box triggers the interlock, shutting down the laser.

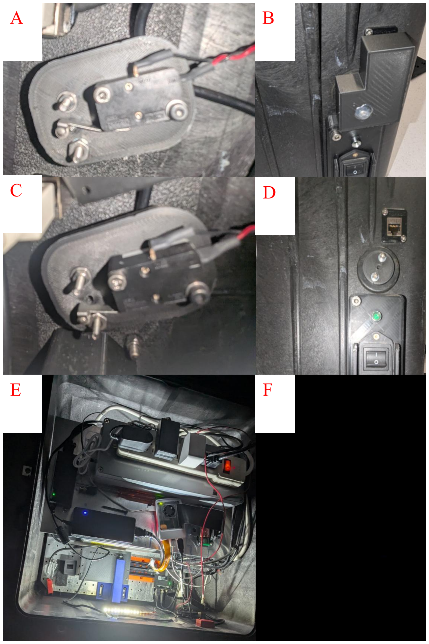
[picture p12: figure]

Figure 3: Photographs of the prototype laser bypass system. (A) Laser bypass activation switch with the external pin inserted, holding down the interlock button. (B) External pin installed through the Ethernet passthrough port, maintaining the interlock in the engaged position during laser startup. (C) Laser bypass activation switch with the pin removed, releasing the interlock button. The actuation lever is positioned below the pin hole, preventing re-engagement of the bypass without opening the enclosure. (D) External view of the passthrough port. (E) System during operation with indicator light on. (F) Open pin port in a dark environment, demonstrating that no light escapes through the port.

3.3.2 Laser purge system:

To ensure that the laser has a constant power output the relative humidity inside the laser head must be kept below 20%, per manufacturer guidelines. A home build dry air purger (purger) is used to control the humidity inside the laser head. The purger consists of a small air pump and an airtight cavity filled with silica gel bead size and an air filter to prevent dust entering the laser cavity. The silica beads are replaced once the laser head humidity exceeds 15% and has been demonstrated to maintain humidity below 20% for ambient humidities as high as 60%.

## 3.4 Crystallization solution:

Two standard biomolecules will be used in this experiment; hen egg-white lysozyme (HEWL) and Glycine. Both the HEWL and glycine solutions have been found to be shelf stable for a minimum period of 14 days. Two plates of each sample will be prepared with rows A and B filled. Row A will be used for laser irradiation while row B will be used as a nonirradiated standard of comparison.
3.4.1 HEWL Preparation:

HEWL was purchased from Sigma-Aldrich will be used without further purification (12650-88-3). Six stock solutions will be prepared by dissolving 100, 200, 400, 600, 800, and 1000 mg of HEWL in 10 mL of 0.1 M acetate buffer (pH 4.35), followed by filtration through a 0.22 μm syringe filter to remove particulates. Each solution will then be pipetted into the wells of a 384-well plate with a glass bottom (Corning® 384-well High Content Imaging Glass Bottom Microplate), completely filling each well. To prevent evaporation, a sterile tape is placed over the top of the plate. The well plate is then mounted inverted in the sample holder, with the glass face pointing towards the focusing mirror.
3.4.2 Glycine preparation:

Glycine was purchased from Sigma-Aldrich (56-40-6) will be used without further purification, and dissolved in heated distilled water at a concentration of 4.6 M. The heated solution was pipetted into the wells of a 384-well plate with a glass bottom. To prevent evaporation, a sterile tape is placed over the top of the plate. The well plate is then mounted inverted in the sample holder, with the glass face pointing towards the focusing mirror.

## 3.5 Control Interfaces:

The laser and translation stages are connected to an intermediate controller (Raspberry Pi) via USB connections. The intermediate controller communicates with the control laptop via Ethernet cable, enabling command execution and status feedback.

## 3.6 Sensor Data Interfaces:

The camera streams, translation stage, and sensor data is measured onto the Raspberry Pi computer. The Raspberry Pi is interfaced using the laptop onboard the aircraft with an ethernet cable through to the inside of the box. As seen in Figure 4, sensor data comes from two breakout boards (an inertial measurement unit and a barometer) assembled into a printed circuit board (PCB) measuring acceleration, velocity, orientation, temperature, pressure, and altitude. Both boards transmit real-time data to the Raspberry Pi via onboard input/output pins.

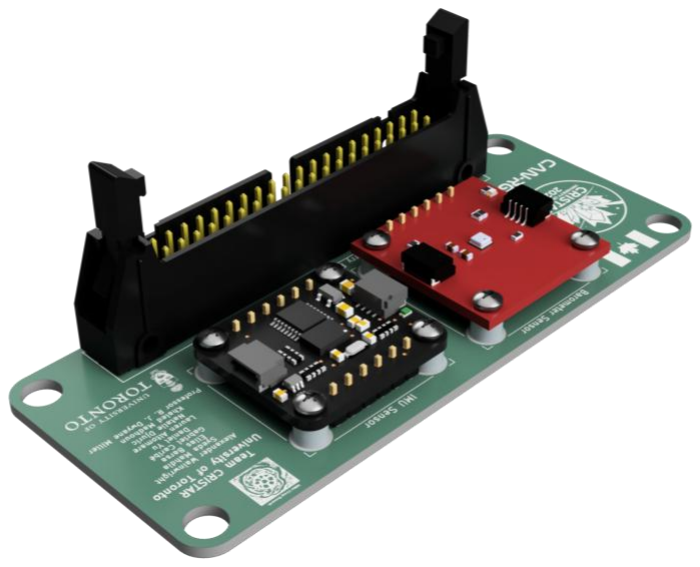
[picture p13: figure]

Figure 4: PCB model holding the two sensor boards.

## 3.7 Cable Management:

The Ethernet cable is routed through a bypass in the Pelican case with strain relief clamps to prevent disconnection during high-g maneuvers. Inside the case, wires are attached to the supporting shelf using Gorilla tape, zip ties, and screw mount cable clips to prevent disconnection and movement during flight operations.

## 3.8 Control and User Interface:

The mission specialist operates the system through a custom graphical user interface (GUI) on the control laptop. The GUI integrates all functions, including laser firing, stage positioning, and real-time monitoring of camera and accelerometer data. The laptop supervises the intermediate controller for laser and stage operations while directly logging sensor data. Data from the accelerometer and camera are time-synchronized and recorded for future reference with crystallization events.

## 4.0 Final Apparatus Design:

Final apparatus was constructed prior to preflight testing. To provide clear images of the design we provide information both on the CAD model and final physical design.

## 4.1 Computer Aided Design Model:

To facilitate design, a full CAD model of the integrated system has been developed. In summary, the system consists of two layers. The lower layer contains the optical and laser apparatus while the upper layer houses the supporting electronics. Figure 5, shows a cut view of the Computer Aided Design (CAD) model, with the position of the laser interlocks within the box shown in Figure 6. The focusing optical mirror, mirror mount and translation stage are shown in detail in Figure 7.

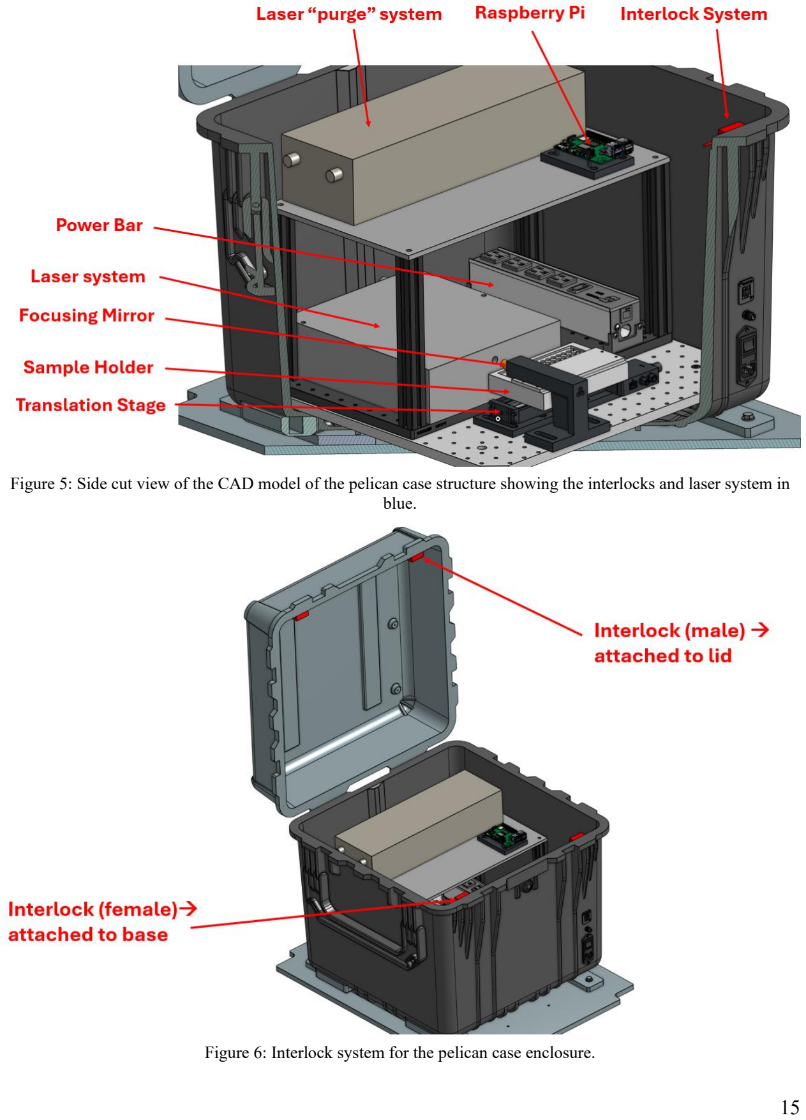
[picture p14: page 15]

Figure 5: Side cut view of the CAD model of the pelican case structure showing the interlocks and laser system in blue.

Figure 6: Interlock system for the pelican case enclosure.

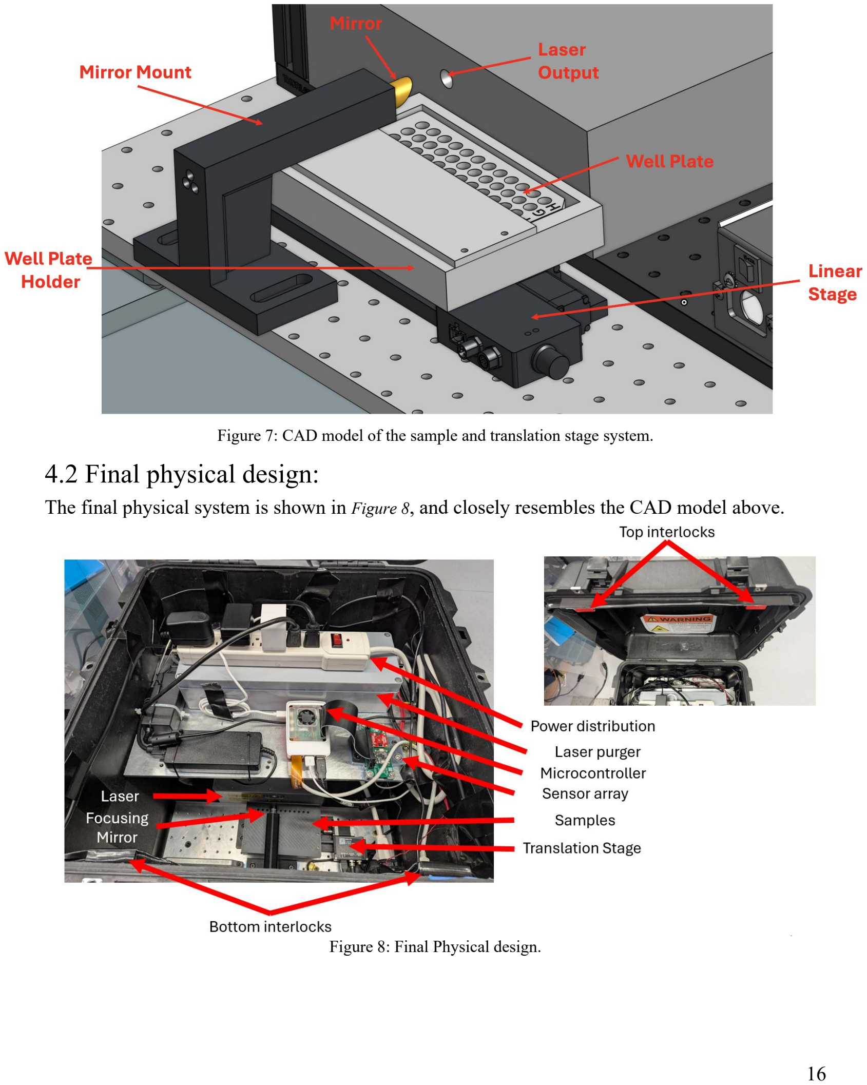
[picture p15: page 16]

Figure 7: CAD model of the sample and translation stage system.

## 4.2 Final physical design:

The final physical system is shown in Figure 8, and closely resembles the CAD model above.

Figure 8: Final Physical design.

## 5.0 Bill of Materials:

Table 1 provides the list of materials to be brought onboard the NRC Falcon 20.

Table 1: Bill of materials for CRISTAR microgravity Flights.

Item Number | Sub System | Item | Description
1. | Optical | Laser | Glucoloop AG IVY Laser (2.1 ns, 2723 nm, 31 mW. 1.5 kHz)
2. | | Mirror Mount | Custom PLA printed plastic mount.
3. Off axis parabolic Mirror

1” EFL, Unprotected gold mirror (MPD019-M03)

4. | | Magnetic Interlocks | ETG-INLK-L & ETG-INLK-R
5. | | Purge system | Home built closed loop air drying system using silica beads and a low power air pump.
6. | Sample | 384 well plate holder | Custom PLA printed plastic
7. | | 384 well plate | Corning® 384-well High Content Imaging Glass Bottom Microplate
8. | | Protein Sample | 25 mg/ml Egg White Lysozyme, 0.3-0.6 M NaCl, 0.05 M acetic acid. 80 µL per well.
9. | | Small Biomolecule Sample | 4.6 M Glycine in distilled water. 80 µL per well.
10. Translation stage

1D Translation stage
(Zaber, X-LSM100A)
11. | Control and monitoring | Raspberry Pi | Raspberry Pi 5
12. | | Laptop | Lenovo IdeaPad Slim 3
13. | | Camera holder | Custom PLA printed plastic
14. | | Camera | Raspberry Pi Camera Module 3
15. | | LED light | LED lighting strip
16. | | Humidity and temperature sensor | SparkFun BME280
17. | | Accelerometer | Adafruit BNO085
18. Power | distribution | Laser Power Supply | 24 VDC, 3.5 A power supply
19. | | Power adapter | See electrical load table
20. | Mis. Experimental Apparatus | Wires | Various gauges
21. | | Fasteners | Various aluminum metric screws.
22. | | Two-Sided Tape | Gorilla Heavy Duty Double Sided Mounting Tape
23. | | Zip Ties | 14-inch Cable Ties Indoor/Outdoor, Model XLS-4.8X370-0-C
24. | | Gorilla Tape | Gorilla Utility Duct Tape
25. Media and | outreach | Cell Phone | Pixel 7, iPhone 13, iPhone 14 Pro Max iPhone 15 Pro Max

## 6.0 Mass Budget:

The mass budget, excluding the pelican case is provided in Table 2. With a total mass of 12.68 kg, less than 30% of the maximum 45 kg total weight is used.

Table 2: Mass Budget for CRISTAR Project.

System | Component | QTY | Unit Mass [kg] | Total Mass [kg] | Fraction of Total [%] | Verification Method
| Mirror Mount 1 0.2 0.2 2% | | | | | M0

Structure and
Mechanisms
384 well plate holder | 1 | 0.1 | 0.1 | 1% | M1
384 well plate | 1 | 0.1 | 0.1 | 1% | M1
Camera holder | 1 | 0.02 | 0.02 | 0% | M0
Power Supply Holder | 1 | 0.1 | 0.1 | 1% | M0
Translation stage | 1 | 0.4 | 0.4 | 3% | M1

Power
Systems
Laser Power Supply | 1 | 0.3 | 0.3 | 2% | M1
9V Power Adapter | 2 | 0.1 | 0.1 | 1% | M1

Translation Stage
Power Supply | 1 | 0.3 | 0.3 | 2% | M1

Raspberry Pi Power
Supply | 1 | 0.1 | 0.1 | 1% | M1

Command and
Data Handling
Raspberry Pi | 1 | 0.1 | 0.1 | 1% | M1
Camera | 1 | 0.01 | 0.01 | 0% | M1
LEDs | 1 | 0.05 | 0.05 | 0%

Optical system

Laser | 1 | 4.3 | 4.3 | 34% | M1
Mirror | 1 | 0.1 | 0.1 | 1% | M1
Purge System | 1 | 4.0 | 4.0 | 32% | M1
Interlocks | 2 | 0.05 | 0.1 | 1% | M1

Misc.

Sample | 1 | 0.0 | 0.0 | 0% | M0
Fasteners | 18 | 0.1 | 1.8 | 14% | M1
Wires | 5 | 0.1 | 0.5 | 4% | E
| | Total Mass: | 12.68 | 100% | E
| | Maximum
| | Mass: | 45 | -
| | Mass
| | Margin: | 32.32 | 72%

## 7.0 Electrical systems:

To enable the experiment, several different electrical systems must be integrated including the laser system, control system, and sensors. Details of the system are described below.
7.1 Schematic: A graphical representation of the electrical system is given in Figure 9. Power supply wires to electrical components are commercially supplied by the manufacturers of the translation stage, raspberry pi and Laser respectively. The laser system and translation stage power supplies have built in surge protection which should be sufficient to prevent damage to the component from fluctuations in the aircraft power. As all power supply and grounding is being done by the commercial manufacturer of commercial-off-the-shelf components used, no additional grounding is planned.

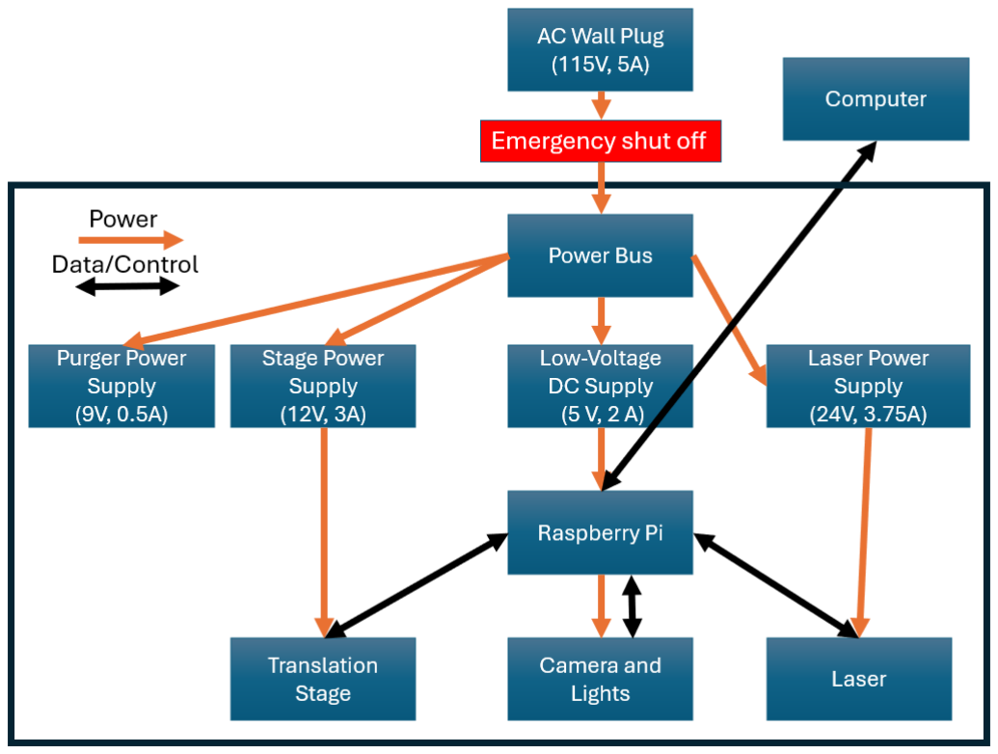
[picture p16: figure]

Figure 9: Graphical representation of the electrical power and control system featuring exclusively commercial off the shelf components.

20

7.2 Load Table:

The total electrical load is broken down by component in Table 3 with a total peak power consumption of 352.4 W, leaving 247.6 W of the available 600 W in reserve.

Table 3: Electrical load table for the CRISTAR project.

Component | QTY | Voltage [V] | Current [A] | Idle Operation | | Science Operation | | Verification

Method Duty Cycle [%]

| | | | | Power
| | | | | [W] | Duty Cycle [%] | Power[W]
Laser | 1 | 24 VDC | 3.75 | 0 | 0.00 | 100 | 90 | M1

Translation
Stage | 1 | 24 VDC | 0.35 | 0 | 0 | 100 | 8.4 | M1

Laptop power
supply | 1 | 120 VAC | 2.00 | 100 | 230 | 100 | 230 | M1

Raspberry Pi
with sensors | 1 | 5 VDC | 3.00 | 100 | 15 | 100 | 15 | M1

Laser “purge”
system | 1 | 9.0 VDC | 0.50 | 100 | 4.5 | 100 | 4.5 | M1
LEDs | 1 | 9.0 VDC | 0.50 | 100 | 4.5 | 100 | 4.5 | M1
Total Power Consumed: [W] | 254.00 | 352.4
Total Available Power [W] | 600.00 | 600.00
Power Margin [W] | +346 | +247.6

7.3 Stored Energy:

No energy storage devices will be used in this RGX project.

21

## 8.0 Science Traceability Matrix Template

Table 4: Science traceability matrix for microgravity laser induced crystallization.

Scientific Objective | Scientific Measurement | Scientific Instrument
Measurement Objective | Measurement Requirement | Instrument | Instrument Requirement
Quantification of crystal size | Determine if gravity changes the crystal size and shape. | Average and maximum crystal size after formation in microgravity, hyper gravity, and normal gravitational conditions. | Electron microscope | Electron microscope resolution below 1 nm. Field of view of 10 µm.
Quantification of crystalline structure and impurities | Determine if gravity changes the crystalline structure. | Crystal lattice structure, lattice spacing, and impurities. | Electron microscope (Diffraction) | System needs to be able to resolve the structure at sub 0.2 nm resolution.

Mission Requirements

The mission specialist must conduct two distinct experimental phases: one under stable 2G hyper gravity conditions and another during microgravity. At the start of each phase, the laser cavitation system, housed within the interlocked chamber, is activated via the GUI on the control laptop to operate continuously for at least 10 seconds on a designated well of the 384-well plate, which is mounted on a motorized translation stage. After each trial, the stage automatically advances to a new well for duplicate trials, ensuring multiple independent samples for both gravity conditions without manual intervention. Throughout both phases, the accelerometer and camera continuously log synchronized data, with each well’s position and corresponding gravity condition recorded for post-flight analysis. The GUI verifies interlock status and operational readiness before each laser activation, and a minimum of three replicates per gravity condition must be completed to ensure statistical validity and reproducibility.

## 9.0 Software System

The control software is a custom application written in Python that runs on the control laptop and serves as the single point of interaction between the mission specialist and the experimental hardware. The software is organized into three components: the graphical user interface (GUI), a backend hardware abstraction library, and the data files generated during operation. The software for the project has been uploaded to a publicly accessible GitHub page (https://github.com/danielz-yu/CRISTAR_UofT_CAN-RGX_9).

9.1 Graphical User Interface: The GUI is built using the Tkinter framework and provides the mission specialist with all the controls and feedback required to operate the experiment. It is divided into four functional regions: a sensor readout panel displaying real-time acceleration, temperature, and humidity values; a platform control panel for selecting and advancing the 384-well plate sample position via the translation stage; a data logging panel for enabling file output and specifying file paths; and an experiment control panel containing the START EXPERIMENT and FIRE LASER buttons. The live camera feed is displayed to the right of the controls, allowing Operator A to monitor sample ablation in real time. The FIRE LASER button is disabled by default and only becomes active once the experiment has been started, which prevents accidental laser activation outside of nominal operation. A keyboard shortcut (Ctrl+F) is also bound to the fire command for rapid actuation during the limited microgravity window. Prior to each run, the GUI verifies that all interlocks are engaged and that environmental conditions fall within predefined ranges before allowing the laser to be enabled.

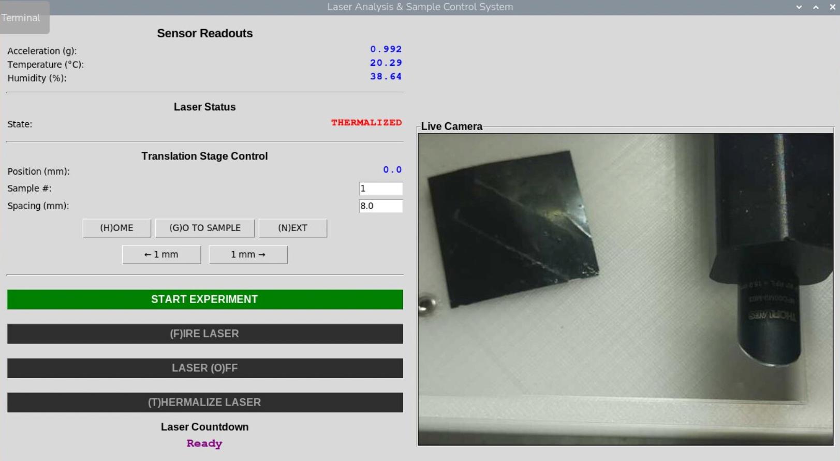
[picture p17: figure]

Figure 10: Graphical User Interface screen shot from GUI demonstration video.

9.2 Hardware Library: A custom Python library (sensors.py) is imported by the GUI and contains all low-level hardware control logic, including commands to drive the linear translation stage, fire the Ivy laser, poll the BME280 and BNO085 sensors, and stream frames from the camera. The sensor polling, camera streaming, laser and translation stage control modules are fully integrated in the GUI on the raspberry pi. The user communicates with the Raspberry Pi over Ethernet, which in turn interfaces directly with the sensor PCB, translation stage, camera and laser. By isolating hardware-specific code in this library, the GUI remains a clean, high-level controller, and any change to a hardware component (e.g. swapping a sensor) requires modification only to the library and not to the GUI itself. If the library fails to import or a hardware device fails to initialize, the GUI continues to run with the affected readouts held at their default values and the failure logged to the console, allowing the operator to diagnose the issue without the application crashing mid-flight.

9.3 Data Files: When data logging is enabled, the GUI creates a timestamped CSV file at the start of each experiment and appends one row per laser firing event. Each row records the timestamp, sample number, three-axis acceleration, velocity, orientation, temperature, pressure, humidity, and altitude, providing a synchronized record of conditions at the moment of crystal nucleation. Acceleration is reported in units of g, with the conversion from the BNO085's native m/s² output performed in software. Camera video is recorded continuously during each parabola and saved as a separate timestamped video file. To satisfy the data segregation requirements of Section 9.2, files generated during hypergravity, microgravity, and level-flight phases are saved into separate folders, each tagged with the parabola number and gravity condition. All data is written to local storage on the control laptop.

9.4 Software Testing: To ensure correct operation of the software control systems, the GUI automatically executes a test program during initialization. This program verifies connectivity to the laser, motion control stage, and sensors before prompting the operator to test keyboard inputs. The testing includes a negative test in which the user is instructed to press random keys to confirm that no system process is inadvertently initiated. The user is also required to press three keys instead of the configured two-key bindings to verify that activation occurs only when exactly two keys are pressed simultaneously. Once these initialization tests are successfully completed, the GUI is considered ready for operator use.

## 10.0 On-Aircraft procedures

In-flight procedures for the mission specialists are provided below for each phase of flight. A flow chart version of these procedures is provided in Appendix C.

## 10.1 Personnel and Responsibilities:

Each flight will be conducted with two designated Mission Specialists, identified as Operator A and Operator B, each with clear responsibilities. This division of responsibilities ensures that neither safety monitoring nor system control is left unattended at any point during the flight. Operator A shall be responsible for:
- GUI Operation
- Laser System Control
- Translation Stage Control
- Camera feedback monitoring
- Data verification
Operator B shall be responsible for:
- Oversight of the physical payload
- Sample Handling
- Monitoring Interlock system and sensors
- Timekeeping throughout each parabolic phase

Both Operators hold equal authority over the emergency stop. The conditions under which the emergency stop shall be engaged are specified in subsection 10.4. All active system control shall be exclusively executed through the custom GUI. The Pelican case shall not be opened during any parabolic manoeuvre until after it is confirmed the system has been fully powered down or the emergency stop has been engaged.

## 10.2 In Flight Procedures: Nominal Operation

10.2.1 System Initialization

While on the ground before taxi but after power is provided to the cabin, both Operators shall complete the following power-on and interlock verification sequence.

1. Operator B shall flip the power switch on the Pelican case to the ON position and confirm that the green LED illuminates, indicating power has been successfully supplied to the system.
2. Operators A and B Shall confirm that the Interlock bypass is engaged inside the box.
3. Operator B will cycle the key on the back of the laser and ensure that the light on the back of the laser is pulsing green.
4. Operator B will then close the box and latch the front two clamps on the pelican case.
5. Operator B will remove the interlock bypass and connect the ethernet cable to the box. Operator A shall confirm the Raspberry Pi has completed its boot sequence.
6. Operator A will then run the “start” in the terminal window. This will run Connection.py code to ensure all systems are operating properly. If the interlock was not initiated properly, return to the start of the initialization procedure (step 1)
7. If the connections are working properly, Operator A will then run Cristar_GUI.py by pressing “y” then the enter key. Operator A shall confirm GUI responsiveness by checking the system readout for error messages and confirming that the sensors are reporting expected start values (i.e. correct positional index of translation stage, all sensors reading nominal ambient values).
8. Operator A will use the GUI to initialize the laser by pressing start experiment. From this point the laser will take 1-5 minutes to stabilize before it can start to emit. This will be indicated by the laser status changing to “Thermalized”. If the system is not thermalized after 5 minutes, the thermalize button will be pressed.
9. After thermalizing, Operator A will perform one test firing of the laser in the homed position to ensure the system is ready for microgravity parabolas. A successful laser firing will be when the red enabled light of the laser turns on, as observed from the camera. If the laser does not fire, the laser thermalize for another 10 minutes before next attempt.
10. After successfully testing the laser emission, both operators shall verbally confirm that the system is powered, interlocks are engaged, and ready before the aircraft begins taxi.

10.2.2 Structure of Parabolic Phases

To maximize the length of the hyper gravity window, the preference for the CRISTAR project is continuous parabolas. Sequential individual parabolas can also work for this experiment if scheduling requires this flight configuration. The ideal flight sequence would be an individual parabola for acclimatisation followed by the sequence of continues parabolas.
Each data parabola of the continuoussequence comprises of three sequential phases: the first hyper gravity pull, the microgravity window, and the second hyper gravity pull. Each phase has a nominal duration of approximately 20 seconds. Accounting for operator reaction times and transition period timing between actions, effective data-collection windows are estimated to be 10-15 seconds per phase. Passing through 1.5 G, the hyper gravity experiments will commence and be terminated. Passing through 0.5 G, the microgravity experiment will commence and be terminated.

10.2.3 Minimum Parabola Requirement

A minimum of 6 microgravity data collection parabolas are required per flight to satisfy the primary scientific objectives of the experiment. This threshold is representative of the minimum sample size necessary to have statistically meaningful analysis of microgravity-induced effects on the sample material.

10.2.4 Acclimatization Parabola

The first parabola of the flight is an acclimatization parabola. No sample data will be collected. Both Operators shall use this period to orient themselves to the flight environment and verify system readiness prior to the start of experimental data collection.

During the acclimatization parabola, the following verification tasks shall be completed:
- Confirm GUI responsiveness and control functionality
- Verify camera feedback and framing
- Verify sensor feedback and expected range of operation
- Execute and monitor the autonomous aiming sequence without laser activation

10.2.5 Data Collection Parabolas

There are an expected 10 data parabolas. The nominal sequence of operations for each data parabola is specified as below.

10.2.5.1 First Hypergravity Pull
1. Both Operators shall issue a verbal ready call, explicitly confirming that all systems and personnel are prepared, prior to entering the hypergravity phase of the parabola. The next steps shall not be initiated until this ready call has been exchanged and acknowledged by both Operators.
2. Operator A shall initiate the run sequence via the GUI by pressing “Ctrl+F” once the force of gravity reaches 1.5g.
3. The system shall autonomously execute the following sequence of events: laser activation per preprogrammed parameters, translation stage advancement to the next sample position and automated stop when the edge of the sample is reached. During this time there shall also be continuous camera recording of the internal system, on which Operator A shall monitor sample cavitation.
4. No manual intervention shall be permitted during hypergravity conditions beyond authorized emergency override commands (see subsection 10.4)

5. Operator B shall monitor the physical state of the payload, note the time the parabola started and monitor the gravity reading on the airplane.
6. After 20 seconds the laser will automatically execute the stop command. In the case where hyper gravity ends before 20 seconds, when gravity returns to 1.5g Operator A shall press “”Ctrl+F” to disable the laser. The system shall disable the laser, cease camera recording, autosave data to a designated folder with appropriate timestamps and advance to the next sample position.

10.2.5.2 Microgravity Window
1. Operator B shall monitor for the onset of microgravity conditions. At 0.5 Operator B will issue a verbal cue to Operator A to start the experiment.
2. Operator A shall initiate the run sequence via GUI by pressing “Ctrl+F”. As outlined in
step 3 of Section 2.4.1, the automated sequence shall enable the laser, initiate camera recording, advance the translation stage to the sample position and execute laser firing per preprogrammed parameters.
3. Operator A shall monitor the live camera feed for laser emission confirmation and bubbling.
4. Operator B shall simultaneously time keep and monitor the gravity sensor on the airplane.
5. After 20 seconds the laser will automatically execute the stop command. In the event that the gravity window is shorter than 20 seconds, Operator B gives a verbal cue that microgravity has reached 0.5g. Operator A will run the stop command (“Ctrl+F”), and the system shall disable the laser, autosave data to a separate folder with timestamps stored separately from the hypergravity datasets, and move the stage to the next position.

10.2.5.3 Second Hyper gravity Pull

In the second hyper gravity pull the operators will follow the same procedure as the first hyper gravity pull.

10.2.6 Level-Flight Stabilization Phase (Inter-Parabolas)

In the event of a need for level flight between parabolas, the following procedure will be used. During the 3-minute phase of level-flight stabilization following a parabola, the system shall be held in a safe standby state with the laser off. The following tasks shall be completed prior to entering the next parabola. The following steps are also equally detailed in Appendix C, Figure 18.
Operator B shall:
1. Confirm the prior run has fully completed and properly terminated.
2. Verify the laser is disabled and the translation stage is stationary.
3. Confirm all data from the preceding run has been labeled and saved appropriately.

Operator A shall:
1. Verify GUI responsiveness.
2. Re-confirm camera framing and feedback stability.
3. Confirm the autonomous aiming sequence is ready.

4. Reset the sample index in the GUI in preparation for the next run.

Laser firing and translation stage motion are prohibited throughout this phase. Within plus or minus 5 seconds from the next parabola as noted by Operator A, both Operators must verbally confirm that all systems are ready to proceed into the next parabolic manoeuvre. This ready call shall be completed prior to entering the hypergravity phase of the upcoming parabola; the parabola shall not be initiated until both Operators have given this confirmation.

10.2.7 Return Transit Flight

After the parabolic sequence is completed, the following procedure will be followed.
1. Operator A shall turn off laser by pressing the laser off button on the GUI (or using the shortcut “Ctrl+O”)
2. Operator A shall ensure the data is logged and saved
3. Operator A will Shutdown the GUI using “sudo poweroff” command in terminal
4. Operator A shall open the Pelican case to ensure the raspberry pi powered down
5. Operator A shall turn off the power pelican case
6. Operator B will confirm that the shutdown procedure has been completed.

## 10.3 In Flight Procedures: Off -Nominal Operation

10.3.1 Transition Criteria

Mission Specialists shall transition to off-nominal procedures upon the observation of any of the following conditions:
- GUI non-responsiveness or loss of system control.
- Absence of laser emission confirmation on the camera feed following initiation of the sequence.
- Anomalous or absent sample response to laser emission inconsistent to expected ablation behaviour.
- Sensor readings outside acceptable operating procedures.
- Translation stage failure to advance to the designated position.
- Camera feed loss or degraded image quality that hinders monitoring.
- Data save failure or absence of expected output files with correct time stamps.
The following corrective steps are also shown in a procedural flowchart in Appendix C, figure 19.

10.3.2 Off-Nominal Corrective Procedures

Upon transition to an off-nominal status, which shall be verbally confirmed between the mission specialists, the following corrective actions shall be executed as applicable during the level-flight stabilization phase only. If a transition to an off-nominal state occurs during the parabola, the Operators shall disable the laser and turn off the system and wait for the level-flight stabilization phase to continue with the following noted corrective procedures.
1. Operator A shall issue a GUI stop command if not already issued to terminate the active sequence. Operator A shall confirm the laser is disabled and the translation stage is stationary.

2. Both Operators shall jointly assess the nature of the issue and determine whether the system can be restored back to nominal operation within the available inter-parabola window of 3 minutes.
3. Operator A shall attempt GUI reset and system re-initialisation as required.
4. Operator B shall verify physical payload and sensor status.
5. If the fault is resolved and both Operators confirm system readiness, nominal operation shall resume for the next parabola.
6. If the fault cannot be resolved within the next inter-parabola window, the affected parabola shall be designated as void and the issue shall be logged for post-flight review.

## 10.4 Emergency Shutdown Procedures

10.4.1 Criteria for Emergency Shutdown

Either Operator shall initiate an Emergency Stop upon observation of any of the following conditions.
- Visible smoke, burning odor, or thermal anomaly within or around the Pelican case and interlock
- Structural failure or physical breach of the experiment enclosure or interlock
- Uncontrolled laser emission or evidence of laser light escaping the enclosure
- Electrical fault, sparking, failure or power anomaly
- Any other condition assessed by either Operator or the flight crew that presents an immediate risk to personnel and the aircraft.

10.4.2 Emergency Shutdown Sequence

Either Operator shall audibly declare “Emergency Stop” to alert the flight crew. Either Operator shall immediately engage the hardware Emergency stop by flipping the power to the pelican case off.
1. Operator A or B shall confirm the power to the box is disabled by looking at the green LED. If power is off the LED will stop illuminating.
2. Operator A shall confirm loss of connection of the computer to Raspberry PI.
3. No further system interaction shall occur until the fault has been assessed and cleared by both Operators in coordination with flight crew.

10.4.3 System Response to Power Loss

In the event of a total power loss to the experiment system, the following states shall be assumed.
1. The laser shall default to a disabled state; no emission shall occur without powered system initialisation
2. The translation stage shall stop all motion and hold its last commanded position
3. The camera shall cease recording, data buffered prior to the power loss might not be recoverable
4. The GUI shall become non-responsive- no system commands can be issued without power and until the system is fully re-initialized.
Power restoration requires full system re-initialization and re-verification of all subsystems prior to resuming operation. Any parabola in progress at the time shall be designated as void.

10.4.4 System response to unplugged laser:

If the laser loses connection with the microcontroller, Operator A will see an error message appear on the GUI. In this event the following process will be followed:
1. Operator A and B will wait for the return to normal gravity and level flight.
2. Operator A will shutdown raspberry pi
3. Operator A Power off box from outside key
4. Operator B will open box, reconnect the laser
5. Follow laser startup procedure.

10.4.5 System response to unplugged microcontroller:

If the microcontroller loses connection with the controlling laptop operator A will see the VNC lose connection. In this event the following process will be followed:
1. Operator A will check external connections and try to re-connect
2. If external connects are checked an not allowing reconnect, Operators must wait at least 20 seconds.
3. Operator B will break the interlock and check internal connections. Operator A will then try to re-connect.
4. Continue checking connections until connection is reset.

10.4.6 Laser Interlock Broken:

If the laser interlock is broken the following procedure must be followed:
1. Operator A will Shutdown raspberry pi.
2. Operator A will power off box from outside key.
3. Follow startup procedure.

## 11.0 Verification and Compliance Matrix

Full Verification and compliance matrix has been uploaded to the TEDP folder (link). (https://docs.google.com/spreadsheets/d/1rBIW-nBx62yPvGunhSp4fAhvphvNBHi9/edit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)

## 12.0 Describe the Structural Verification procedure:

## 12.1 Physical Testing

PLA printed parts were printed in batches of three. One for destructive load measurement to find ultimate strength. One for non-destructive testing to a load of 3G with repeated cycling of weight on and off for 10 second intervals for 20 seconds each. Finally, one spare part were printed at the same time. If the part needs to be redesigned, the parts ware printed again at the same time. Parts was tested using standard weights from the department of Physics at the University of Toronto. If the required weight exceeded the weights available from the standard weights sets, water at set volumes was added to a jug to create the required loads.

All commercially purchased parts were tested with the load of 3G to ensure correct operations under this load. This was accomplished by using a standard of weights for 5-minute load period followed by cycling the weight on and off for five 20 second intervals.

12.1.1 Yield Point Determination of PLA Mounts

Two PLA mirror mounts from the same print batch were tested in a cantilever configuration replicating the mirror with a controlled load (see Figure 11). The base of each mount was clamped to the edge of the baseplate and load was applied vertically at the free end of the cantilever arm via filling a jug with water (jug + lid = 136 g). Deformation was measured as the reduction in vertical distance from the free end of the mount arm to the surface of the baseplate using a digital caliper (±0.05 mm resolution). As the load was applied via a monofilament fishing line, a small amount of elastic elongation of the line may have contributed to the measured displacement. Consequently, the measured deflection represents a conservative estimate of mount deformation, as any line stretch would slightly overestimate the true deflection of the PLA mount.

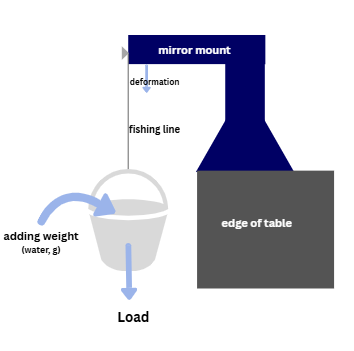
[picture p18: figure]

Figure 11: Mirror Mount Setup for Yield Point Determination and Load Testing.
Load was applied incrementally from 136 g to 4136 g total applied load. The functional yield threshold was defined as 0.5 mm deflection from the unloaded reference position, consistent with the alignment tolerance of the optical system. This threshold was first exceeded at a total applied load of 2036 g (19.97 N), resolved well above the ±0.07 mm uncertainty floor. A linear regression across the full dataset yielded R² = 0.597 and a stiffness of 42.5 N/mm, confirming elastic behaviour throughout the testing regime (see Figure 12). The operational load on the mirror mount is 63.2 g (0.62 N), which corresponds to the mass of the gold off-axis parabolic mirror under 1G, giving an experimental factor of safety of 44.7. This substantially exceeds the program requirement of 1.5 per RGX-PHY002-A.

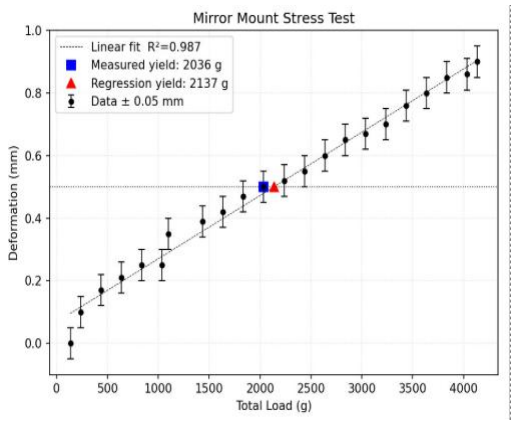
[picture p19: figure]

Figure 12: PLA Mirror Mount Deformation under incremental cantilever loading. Dashed line indicates the 0.5mm functional yield point as defined.
12.1.2 Cyclic Loading

Cyclic loading was conducted on two mounts printed in different orientations. One printed paralleled to the base of the mount, and one printed perpendicular to the base of the mount. After unloading after yield testing, both mounts returned to their original positions with no observable permanent deformation. Both mounts were then cycled at the full proof load of 4136 g (40.56 N), comprising 4000 g added mass plus the 136 g jug and lid, for 10 cycles at 20 ± 0.1 seconds per cycle per RGXPHY002-A.

The mount printed parallel to the base of the mount deformed 0.74 mm statically under this load. It was subsequently dropped from 3 inches with the full container attached and failed at the base and was removed from consideration. The mount printed perpendicular to the base deformed 0.91 mm statically under the same load. After 10 cycles the position shifted by 0.01 mm, which is within the ±0.07 mm measurement uncertainty. No progressive deformation was observed. The perpendicular print did not fail under the subsequent 3-inch drop test with a full container.

The perpendicular printed mount was selected for flight. Static deformation under the 3G proof load is 0.91 ± 0.07 mm with no measurable change after cyclic loading, satisfying RGXPHY002-A.

## 12.2 Electrical Verification procedure:

A 600 W, 115 V, 5 A uninterrupted power supply was used to power the pelican case for ground testing. This apparatus will also be used for testing complete power loss to show the system defaults into a safe condition. The initial test took place on March 10th, 2026. Our results showed that the laser became disabled and the translation stage locked when the power was cut showing that there are no hazardous conditions created.

## 12.3 Ground Test procedure:

Ground testing, to the fullest extent possible, followed the same process as the flight procedure. (The ground test video is linked here for review.) (https://drive.google.com/drive/folders/162ZAsvBycXtN1HuH8puPMYJ3LtQqZAbr?usp=drive_link) Operator B was responsible for overseeing the physical payload, sample handling, monitoring the interlock, sensors, and timing. Operator A handled all GUI operations, which included laser control, translation stage control, camera feedback monitoring, and data verification. Prior to the ground test, the system was inspected by both operators to ensure the configuration matched flight operations.

Prior to the start of the ground test, the 384-well plate was prepared and placed in the box. The ground test was conducted in a laser-safe laboratory, with both operators having completed the University of Toronto Laser Safety Course. To simulate operations during the parabolas, a laptop was placed on top of the Pelican case, and the top holes were covered with electrical tape.

To simulate the first parabola for data collection, Operator B confirmed that the experiment was properly set up, carefully noting stage position, laser readiness, and sample positioning. Operator A confirmed that the GUI and its controls were responsive, the camera framing and feedback were ready, and the sensors were functioning as expected.

Both operators verbally agreed to proceed before Operator A initiated the run sequence with the laser enabled in the GUI. The laser fired within the Pelican case according to preprogrammed parameters, the translation stage autonomously advanced to the designated sample position, and the camera feed recorded continuously to monitor both the internal system and sample ablation. Operator B monitored the physical state of the payload, maintained timekeeping, and tracked the sensors. Both operators verbally confirmed readiness, Operator A initiated the run through the GUI, and the laser firing, autonomous stage movement, and camera recording sequence proceeded identically. No manual intervention occurred during the simulated "hypergravity" conditions, which were modeled by a 20-second delay during which the operators could not intervene in the Pelican case's operation.

After the 20-second pause, Operator B monitored the gravity cue (orally confirmed during the ground test) and, within ±2 seconds of "confirmed microgravity," verbally cued Operator A to press “Laser Fire” in the GUI. The simulated microgravity window lasted approximately 20 seconds. The automated sequence enabled the laser, started camera recording, and commanded the stage to advance to the current sample position, where the laser fired according to the preprogrammed exposure parameters. Operator A monitored the live camera feed for confirmation of laser emission and visible sample response, such as bubbling, while Operator B simultaneously monitored the physical payload. Upon completion, the laser was disabled, stage motion ceased, and data were automatically saved to a specified folder on the computer with timestamps.

To simulate the conditions that would occur if the microgravity and hyper gravity windows where shorter than 20 seconds, the tests were completed again with the operator manually ending the irradiation process using the “stop” input on the GUI.

The second simulated hypergravity (2G) pull was represented by another 20-second pause, during which the operators could not interact with the experiment.

The ground test was considered successful when all wells were successfully irradiated by the laser and crystals were successfully harvested from the well plate.

## 12.4 Additional Verification:

As our system is laser based, we demonstrated that the enclosure is both light tight and that the laser cannot be active if the box is open. Details on laser safety calculations are provided in Appendix B. To facilitate this testing the following two verifications are required:

12.4.1 Dark room testing of the light tight box:

To show that the box is light tight, the box was placed in a dark room in the department of physics at the University of Toronto. While in the dark room, a bright LED array was placed inside the box with the lid opened. The room lights will then be turned off. A video was then be started showing the bright light in the box. With the video recording, the box was closed, and a white sheet of paper was moved around the box to look for any escaping light. This test successfully showed that no light escaped the box. (Video link) (https://drive.google.com/file/d/19HIyNxzSfmuVZ-DzX0mEZN01Lg1H8o5C/view?usp=drive_link)

12.4.2 Laser interlock testing:

To show that the interlock system works, we will first demonstrated on the manufacturer’s GUI that the interlock is triggered when the box is open or closed. Then, in a laser safe lab, we will enable the laser with the box closed, with the laser illuminating a Photodiode sensitive to the Mid-IR. With the box opened during laser operations we will check using an oscilloscope that the laser did cease operations when the box was open and did not restart operations when the box closed until the user initiated the start of the laser. After successfully showing that the interlock worked, the following video was taken to show the interlock in action. (Video link) (https://drive.google.com/file/d/1nRDf8SOl7icMweWo-p6q1BDWHla83alf/view?usp=drive_link)

## 13.0 Hazard Analysis Report

Efforts have been made to minimize the risks and hazards associated with the CRISTAR experiment. However, some residual risks remain. The hazards present in this experiment can be broadly categorized into three groups: chemical, electrical, and optical. Details of each hazard category and the associated mitigation strategies are summarized in Tables 5-10 below.
Chemical hazards can include exposure to corrosive substances, toxins, or other hazardous reagents. In this experiment, samples are prepared using non-hazardous chemicals wherever possible. The primary sample being crystallized is hen egg white lysozyme, which is non-toxic and generally considered non-hazardous under standard laboratory handling conditions. The sample is dissolved in a salt solution that is also non-toxic and non-hazardous in nature. Relevant Safety Data Sheets (SDS) for all chemicals used in the experiment are provided in Appendix D. Details on the major identified hazard of a sample spill are outline in Table 5.

Table 5: Protein Crystallization solution spills.

Hazard: Sample solution spills

Description of Hazard to Scientific Outcome | Description of Hazard to Crew or Aircraft Safety

Experiments cannot be performed if the sample is not contained.

Description of Hazard Control and Mitigation Plan

Possibility of the solution leaving the enclosed sample container during flight. This is mitigated by using non-hazardous samples, chicken egg white lysozyme and glycine (see SDS sheets in Appendix), having full enclosure inside the box and having a sample that is water soluble to protect equipment.

Cease Test Criteria:

If the solution is seen outside the container on the camera, stop the test.

Terminate Flight Criteria:

NA

Electrical hazards include the potential for overload, short circuits, and heating of electrical components. These risks are mitigated by operating all electrical units well below their maximum current and voltage ratings. Additionally, proper wiring practices and rated components are used to ensure safe operation throughout the experiment. Details on these hazards are listed in Tables 6 and 7.

Table 6: Power loss hazard table.

Hazard: Loss of power

Description of Hazard to Scientific Outcome | Description of Hazard to Crew or Aircraft Safety
If power to the system is lost mid-flight, the experiment cannot be conducted. | NA

Description of Hazard Control and Mitigation Plan

If the power cable gets disconnected during flight or if the internal power bar comes disconnected the experiment will not operate.

Cease Test Criteria:

If power is lost during a test, cease the test and identify the loss of power. If the green light on the box is on, cease the test. If the green light on the box is off. Look at the plug to identify if it is plugged in. Cycle the power switch to see if power is restored. If power is restored, continue with the next parabola.

Terminate Flight Criteria:

NA

Table 7: Translation stage failure hazard table.

Hazard: Translation stage failure

Description of Hazard to Scientific Outcome | Description of Hazard to Crew or Aircraft Safety
If the translation stage fails only one sample can be produced per flight | NA

Description of Hazard Control and Mitigation Plan

The selected translation stage is durable and can be manual operated. Prior to the flight the translation stage will be tested to ensure functionality. If the stage becomes inoperable during the flight, the stage should be reset and tested again.

Cease Test Criteria:

Stage is unable to move. Cease test.

Terminate Flight Criteria:

NA

Optical hazards arise from the use of laser radiation within the experimental system. These risks are mitigated through the implementation of appropriate safety measures, including interlock systems, controlled beam paths, and adherence to established laser safety protocols. These measures are intended to prevent accidental exposure to laser radiation during operation. Details on these hazards are listed in Tables 8-10.

Table 8: Loss of Connections with laser.

Hazard: Loss of Connections with laser.

Description of Hazard to Scientific Outcome | Description of Hazard to Crew or Aircraft Safety
Unable to stop the laser from irradiating samples adds uncertainty to laser parameters used on the samples. | Unable to determine if the laser is operating can pose a laser safety risk.

Description of Hazard Control and Mitigation Plan

If connection is lost to the laser when the laser is operating this poses an experimental hazard as the irradiation time of the sample will not be known and a laser safety hazard as the condition of the laser is unknown. To mitigate the risk, if the laser connection is lost power to the box must be cut off, ceasing the experiment.

Cease Test Criteria:

If the laser connection is lost power to the box mut be cut off, ceasing the experiment.

Terminate Flight Criteria:

NA

Table 9: Structural failure or deformation of the Mirror Mount.

Hazard: Structural failure or deformation of the Mirror Mount

Description of Hazard to Scientific Outcome | Description of Hazard to Crew or Aircraft Safety
Deformation of the mirror mount during flight may cause laser light to not hit the intended location on the well plate. | NA

Description of Hazard Control and Mitigation Plan

Mirror mount changes location by more than 0.5 mm. the mirror mount has a much higher factor of safety (over 50) than other components. As such, mirror deformation should not occur.

Cease Test Criteria:

If the mirror mount is seen deforming on the camera and cavitation ceases prematurely, end the test.

Terminate Flight Criteria:

NA

Table 10: Loss of laser light confinement risk table.

Hazard: Loss of laser light confinement

Description of Hazard to Scientific Outcome | Description of Hazard to Crew or Aircraft Safety
Cavitation would cease, preventing crystal formation. | Potential for laser injuries to crew if the laser light is allowed to escape the confinement of the pelican case.

Description of Hazard Control and Mitigation Plan

Possibility for laser light to escape the optical set up, and the pelican case enclosure. This is mitigated through making the box light tight, use of fixed optics, non-reflective surfaces in the box and the use of interlocks to prevent laser operations if the box is open. During level flight before and after the parabolas the laser system will be disabled. Under normal operation, the enclosure and safety interlocks ensure the system operates as a Class 1 laser product and laser safety eyewear is not required. Operators will be provided with OD5+ laser safety goggles for use only during servicing, alignment, or other procedures where the enclosure is open or safety interlocks are intentionally defeated, as described in Appendix B. These procedures will not occur after departing UofT as they require a laser safe lab.

Cease Test Criteria:

If the interlocks are triggered or the internal mirror is misaligned, cease the test. If the light is seen escaping the box, testing will cease.

Terminate Flight Criteria:

NA

## 14.0 Ground Support and Crew Assistance

## 14.1 Specialised Equipment:

To preserve the HEWL and glycine crystallization samples formed during the microgravity experiments, a room temperature storage approach at 20°C will be maintained throughout transport and handling. To this end, we intend to bring a Styrofoam container as soon as possible following the flight. To this end, a Styrofoam container will be used at the campaign site to store the 384-well plates both prior to and following flight operations. All samples will remain sealed within the closed 384-well plates to prevent evaporation and unintended crystallization effects, which is common for HEWL and glycine samples. The well plates will be prepared in advance at the University of Toronto and transported to the campaign site. A small dino-lite microscope will be used to look at the wells immediately after the flight to see if crystals formed.

## 14.2 Ground Crew Procedures:

14.2.1 Prior to arrival at Campaign site: The ground crew will be responsible for preparing the samples prior to departure from the University of Toronto. The time when the solution and supernatant are mixed will be noted. The ground crew will be responsible for the transportation of samples to and from the campaign site.
14.2.2 Prior to Flight: Samples will be brought to the ground crew by the flight crew and loaded by the flight crew and preflight testing will be conducted by the flight crew. The time of mixing will be reported to the flight and ground crew (accurate to the nearest minute).
14.2.3 Post Flight: The ground crew will collect the well plate from the flight crew, ensuring the samples are appropriately sealed, and place them into the Styrofoam container for transportation. Upon return to the lab, samples will be immediately cryo-preserved on SEM grids using a Leica GP2.
Note: Samples should be collected from the 384 well plate within 1 week of production. The impact of immediate and delayed extraction from the 384 well was investigated and it was determined that the crystal structures and solution would be stable for up to seven days.

## 15.0 Technical Risk Assessment

Potential points of failure for the project are outlined in detail in Appendix A. The summary of the risk assessment table is shown in the risk assessment matrix below (Table 11). We note that most of the failure modes that would result in an unsuccessful experiment are technical in nature. These risk assessment points are mitigated through a combination of engineering design and ensuring replacement parts for critical components are available at the campaign site.

Table 11: Risk Assessment Matrix.

Probability

Low | Med | High

Severity

High | MR1, TR1, TR2,
| TR3, TR4
Med | HR2, HR3, TR6 | MR2, MR3
Low | TR5 | | HR1

## 16.0 Project Management
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

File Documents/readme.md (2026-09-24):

# CRISTAR — CAN-RGX 9

## Project Documentation

This repository contains the primary project-management, proposal, design, and review documentation for **CRISTAR**, the University of Toronto team participating in the **Canadian Reduced Gravity Experiment Design Challenge (CAN-RGX 9)**.

CRISTAR investigates **laser-induced crystallization under reduced- and increased-gravity conditions**. The experiment uses a compact laser-cavitation system to generate lysozyme crystals during parabolic flight aboard the National Research Council of Canada's Falcon 20 research aircraft. The resulting crystals are characterized to investigate how gravity influences crystal morphology and structure.

CAN-RGX is a Canadian student research competition conducted in collaboration with the **National Research Council of Canada (NRC)** and the **Canadian Space Agency (CSA)**. Selected teams progress through proposal development, project management, preliminary and critical design reviews, testing, flight-readiness activities, and experimental flight operations. :contentReference[oaicite:0]{index=0}

## Repository Contents

### `Cristar - Proposal Feedback.pdf`

Feedback received on the CRISTAR proposal during the CAN-RGX 9 selection process.

This document provides the external assessment and recommendations that informed the subsequent development of the experiment and project documentation.

### `Cristar_RGX_9_Proposal.pdf`

The original CRISTAR proposal submitted for CAN-RGX 9.

The proposal describes the scientific motivation, experimental concept, proposed methodology, expected outcomes, and relevance of investigating crystallization under altered-gravity conditions.

CRISTAR was selected as one of four teams for CAN-RGX 9, alongside teams from the University of British Columbia and University of Waterloo. :contentReference[oaicite:1]{index=1}

### `CRISTAR Project Management Plan.pdf`

The Project Management Plan (PMP) developed following team selection.

The PMP establishes the project's organizational structure, responsibilities, schedule, milestones, risk-management approach, and project-management framework for progressing the experiment from concept through flight.

The CAN-RGX 9 program followed a structured engineering-development process including a Project Management Presentation, Preliminary Design Review (PDR), Critical Design Review (CDR), Test Equipment Data Package (TEDP) submissions, Ground Test Video, and Flight Readiness Review (FRR). :contentReference[oaicite:2]{index=2}
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

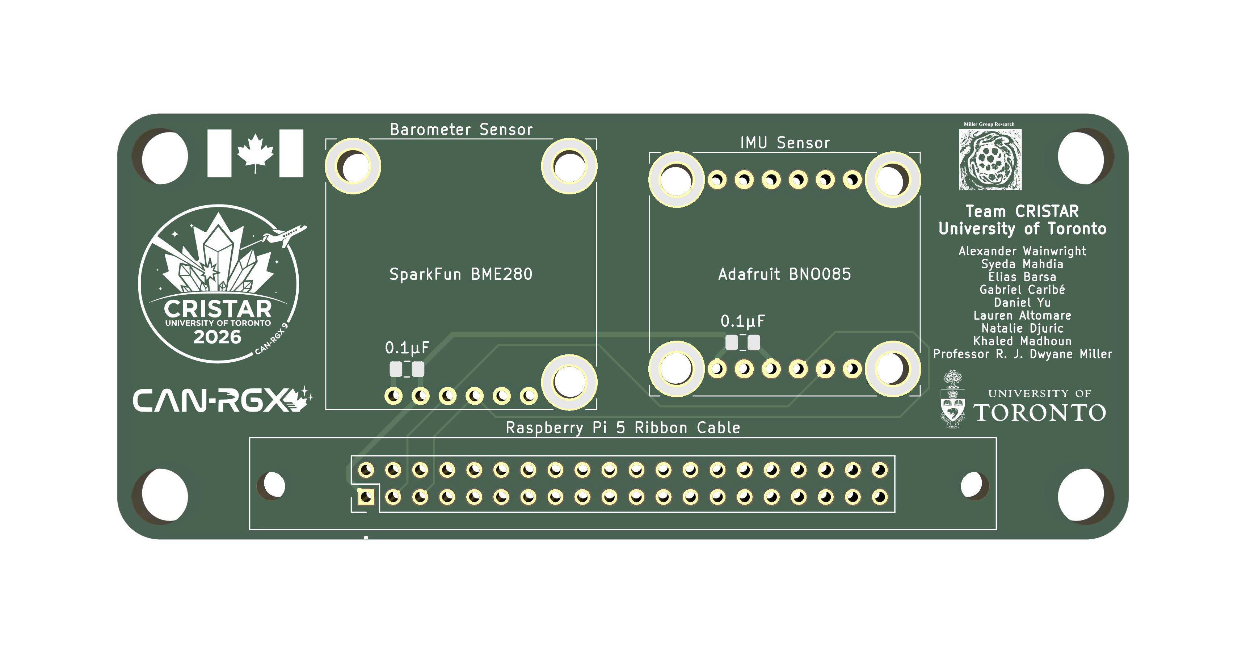
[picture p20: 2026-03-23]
pcb_design/cristar_sensor_board_top.png

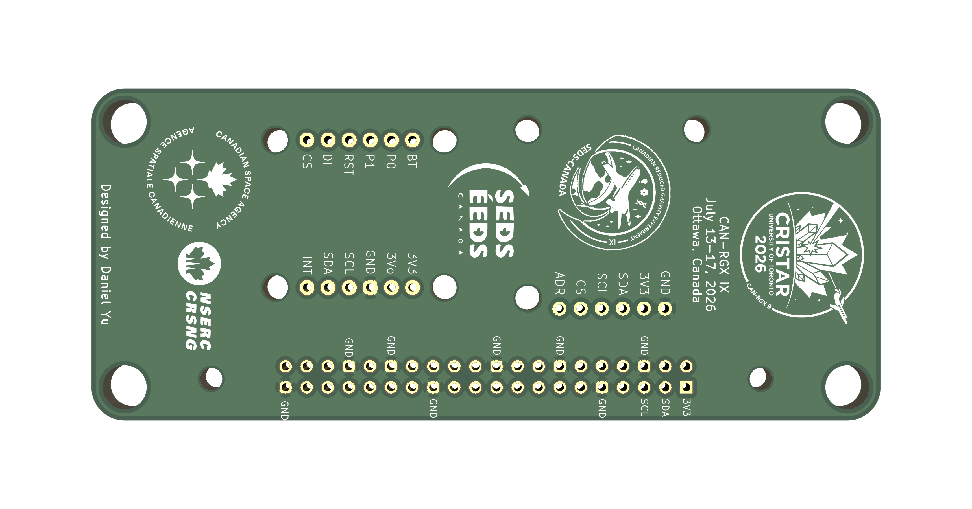
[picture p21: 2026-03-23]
pcb_design/cristar_sensor_board_bottom.png

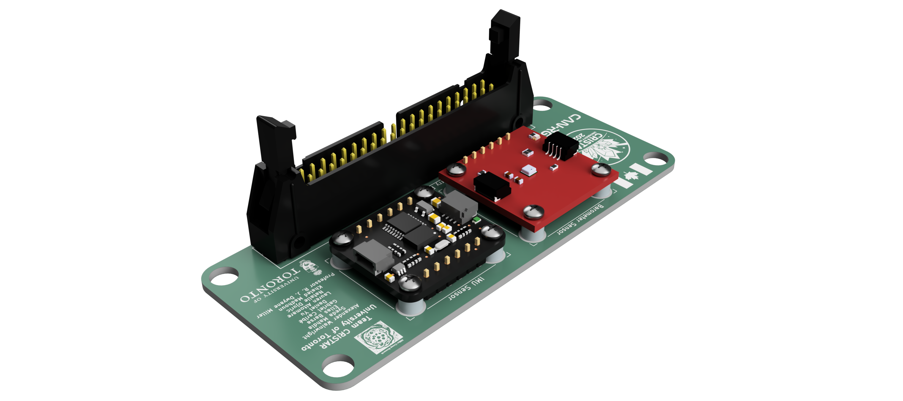
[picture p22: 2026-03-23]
pcb_design/cristar_sensor_board_render.png

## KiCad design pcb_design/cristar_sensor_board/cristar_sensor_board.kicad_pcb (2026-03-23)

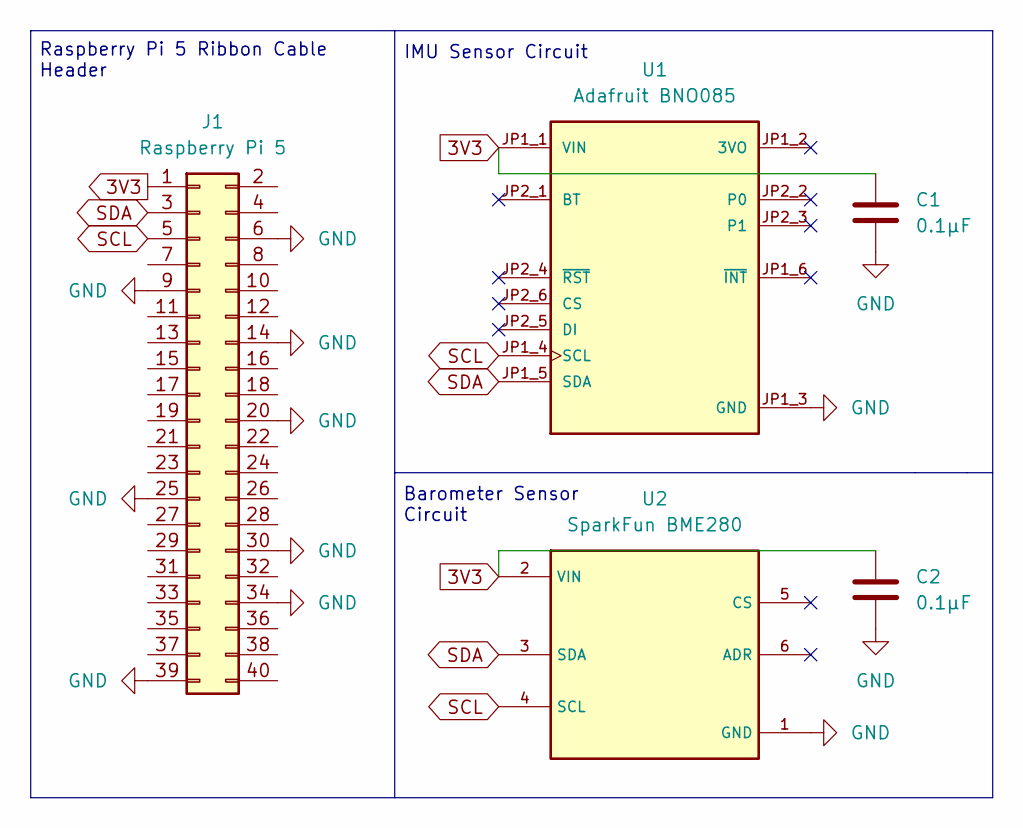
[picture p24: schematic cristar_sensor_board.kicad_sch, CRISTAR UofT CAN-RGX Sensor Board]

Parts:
C1, C2: 0.1µF; C_0805_2012Metric_Pad1.18x1.45mm_HandSolder
J1: Raspberry Pi 5; 3M_D3432-6302-AR
U1: Adafruit BNO085; Adafruit_BNO085; PARTREV 2021-03-16
U2: SparkFun BME280

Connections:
3V3: C1.1, C2.1, J1.1, U1.JP1_1 (VIN), U2.2 (VIN)
GND: C1.2, C2.2, J1.6, J1.9, J1.14, J1.20, J1.25, J1.30, J1.34, J1.39, U1.JP1_3 (GND), U2.1 (GND)
SCL: J1.5, U1.JP1_4 (SCL), U2.4 (SCL)
SDA: J1.3, U1.JP1_5 (SDA), U2.3 (SDA)

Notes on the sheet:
Raspberry Pi 5 Ribbon Cable Header
IMU Sensor Circuit
Barometer Sensor Circuit

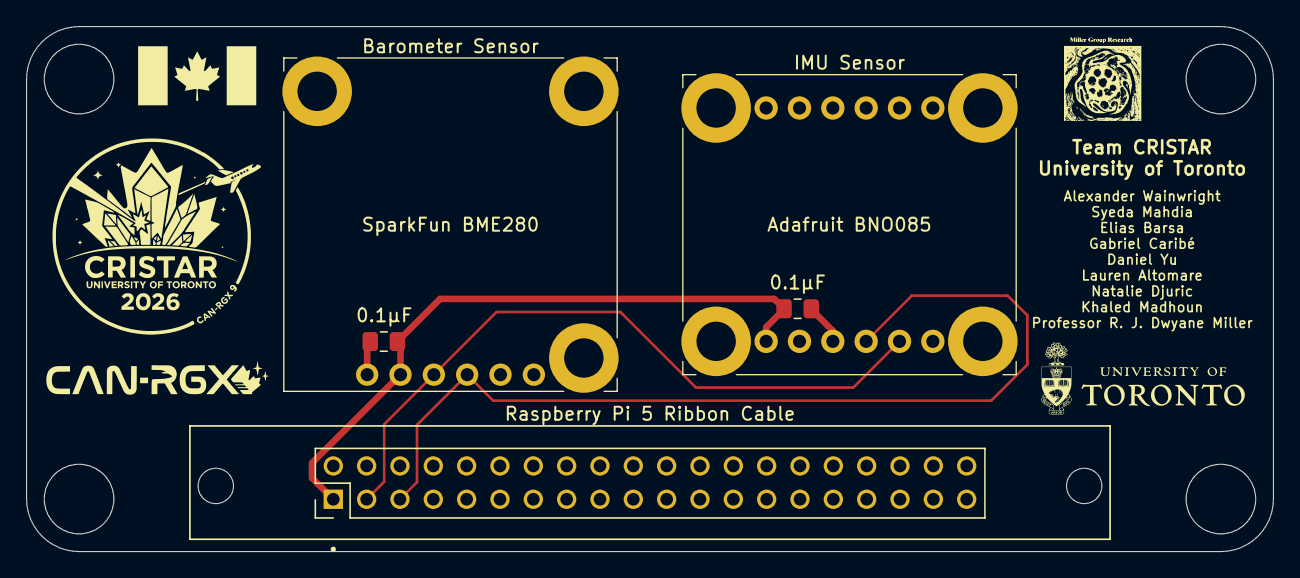
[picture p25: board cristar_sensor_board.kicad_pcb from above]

Board: 2 copper layers, 95.0 x 40.0 mm, 5 parts (0 on the bottom side), 4 nets.

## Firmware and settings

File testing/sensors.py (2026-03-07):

import time
import board
import busio

from adafruit_bme280.basic import Adafruit_BME280_I2C

from adafruit_bno08x import (
    BNO_REPORT_ACCELEROMETER,
    BNO_REPORT_GYROSCOPE,
    BNO_REPORT_ROTATION_VECTOR
)

from adafruit_bno08x.i2c import BNO08X_I2C


def init_i2c():
    return busio.I2C(board.SCL, board.SDA, frequency=400000)


def init_bme280(i2c):
    bme280 = Adafruit_BME280_I2C(i2c, address=0x77)
    bme280.sea_level_pressure = 1013.25
    return bme280


def init_bno085(i2c):
    bno = BNO08X_I2C(i2c)

    bno.enable_feature(BNO_REPORT_ACCELEROMETER)
    bno.enable_feature(BNO_REPORT_GYROSCOPE)
    bno.enable_feature(BNO_REPORT_ROTATION_VECTOR)

    return bno


def main():

    print("Initializing I2C...")
    i2c = init_i2c()

    print("Initializing BME280...")
    bme280 = init_bme280(i2c)

    print("Initializing BNO085...")
    bno = init_bno085(i2c)

    print("Sensors ready\n")

    while True:

        try:

            # ----- BME280 -----

            temperature = bme280.temperature
            humidity = bme280.relative_humidity
            pressure = bme280.pressure
            altitude = bme280.altitude

            # ----- BNO085 -----

            accel_x, accel_y, accel_z = bno.acceleration
            gyro_x, gyro_y, gyro_z = bno.gyro
            quat_i, quat_j, quat_k, quat_real = bno.quaternion

            print("====== WEATHER DATA ======")
            print(f"Temp: {temperature:.2f} C")
            print(f"Humidity: {humidity:.2f} %")
            print(f"Pressure: {pressure:.2f} hPa")
            print(f"Altitude: {altitude:.2f} m")

            print("\n====== IMU DATA ======")
            print(f"Accel (m/s^2): {accel_x:.3f}, {accel_y:.3f}, {accel_z:.3f}")
            print(f"Gyro (rad/s): {gyro_x:.3f}, {gyro_y:.3f}, {gyro_z:.3f}")
            print(f"Quaternion: {quat_i:.3f}, {quat_j:.3f}, {quat_k:.3f}, {quat_real:.3f}")

            print("\n-----------------------------\n")

            # time.sleep(2)

        except Exception as e:
            print("Error:", e)
            # time.sleep(2)


if __name__ == "__main__":
    main()

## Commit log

2026-03-06 Initial sensor prototype code
2026-03-07 Fixing I2C in sensors.py, libraries required in requirements.txt, and adding basic sensor outputs for main GUI
    [sensors.py]
2026-03-07 Documenting RaspPi5 GPIO pin connections
2026-03-23 Adding PCB files and renders
    [cristar_sensor_board-B_Cu.gbr, cristar_sensor_board-B_Mask.gbr, cristar_sensor_board-B_Paste.gbr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]
2026-03-23 PCB update
2026-03-23 Adding new PCB render
